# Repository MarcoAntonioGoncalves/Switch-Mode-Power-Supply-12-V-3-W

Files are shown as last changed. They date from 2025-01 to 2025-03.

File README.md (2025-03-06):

# Switch-Mode-Power-Supply-12-V-3-W

## Introduction

My name is Marco Antonio Machado Gonçalves, and I am a Mechatronics Engineering student at the Universidade Federal do Paraná (UTFPR). I created this repository to help anyone interested in designing a switched-mode power supply. It provides a comprehensive step-by-step guide, including the underlying theory, key equations, and criteria for selecting components. The repository also includes the circuits implemented on the PCB, along with the schematic and board files, as well as simulations and the results obtained

I think it’s important to highlight that the theoretical part does not provide an in-depth analysis of the mesh and operational stages of the circuits. As a consequence, the deduction of the design equations is also not presented. What is expected to be found in the theory is an explanation of how the circuit works and the necessary equations for designing it.

I would like to give credit to the book [Projeto de Fontes Chaveadas](https://ivobarbi.com.br/livro-projetos-de-fontes-chaveadas/) written by Ivo Barbi, and the YouTube playlist [Fontes Chaveadas](https://www.youtube.com/watch?v=BYBMHBqT8EI&list=PLSjlUAuQORNNm-O2ilwZME7qL0d8M-_xs). The book was a great help in the rectifier project and Dc-Dc converter project, while the YouTube channel provided detailed explanations and information about the design of switched-mode power supplies and high-frequency inductors. If anyone wants to dive deeper into the theory, I recommend these two sources.

## Recomendend order to read the repository

1. **Theory**
   - Start with the theoretical section to understand the main concepts.

2. **Simulations**
   - Review the simulations made in PSIM.

3. **Component Selection**
   - After the simulations, analyze the component selection.

4. **Results**
   - Explore the obtained results to understand the actual performance.

5. **Hardware Folder**
   - The hardware folder contains the following files:
     - Schematics
     - PCB files
     - 3D image of the PCB
   - These files are especially useful for those interested in building their own power supply.

## Specifications

<table align="center">
  <thead>
    <tr>
      <th><strong>Specification</strong></th>
      <th><strong>Description</strong></th>
      <th><strong>Unit</strong></th>
    </tr>
  </thead>
  <tbody>
    <tr>
      <td>Minimum Input Voltage</td>
      <td>110</td>
      <td>V</td>
    </tr>
    <tr>
      <td>Maximum Input Voltage</td>
      <td>233</td>
      <td>V</td>
    </tr>
    <tr>
      <td>Minimum Peak Voltage</td>
      <td>155.56</td>
      <td>V</td>
    </tr>
    <tr>
      <td>Maximum Peak Voltage</td>
      <td>329.51</td>
      <td>V</td>
    </tr>
    <tr>
      <td>Grid Frequency</td>
      <td>60</td>
      <td>Hz</td>
    </tr>
    <tr>
      <td>Output Power</td>
      <td>3</td>
      <td>W</td>
    </tr>
    <tr>
      <td>Output Voltage</td>
      <td>12</td>
      <td>V</td>
    </tr>
    <tr>
      <td>Efficiency</td>
      <td>80</td>
      <td>%</td>
    </tr>
    <tr>
      <td>Rectifier Ripple</td>
      <td>5</td>
      <td>%</td>
    </tr>
    <tr>
      <td>Switching Frequency</td>
      <td>66</td>
      <td>kHz</td>
    </tr>
    <tr>
      <td>Inductor Ripple</td>
      <td>0.25</td>
      <td>%</td>
    </tr>
    <tr>
      <td>Output Voltage Variation</td>
      <td>0.01</td>
      <td>V</td>
    </tr>
    <tr>
      <td>Safety Coefficient</td>
      <td>1.25</td>
      <td>-</td>
    </tr>
    <tr>
      <td>Ambient Temperature</td>
      <td>50</td>
      <td>ºC</td>
    </tr>
  </tbody>
</table>

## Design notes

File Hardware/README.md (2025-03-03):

# HADWARE

This session contains the hardware project files for the switch-mode power supply. The software used was Fusion 360. The files for download and images have been provided.

The objective was to design hardware that could be manufactured in a DIY manner, so the PCB contains larger pads and traces than would normally be necessary.

The method used for fabrication was the photographic method, which involves coating the copper board with photo-sensitive paint and transferring the circuit using ultraviolet light.

Below are images of the top and bottom layers of the PCB after fabrication. Unfortunately, the solder mask on the bottom layer had some defects, but it still served its purpose of facilitating the soldering process.

<p align="center">
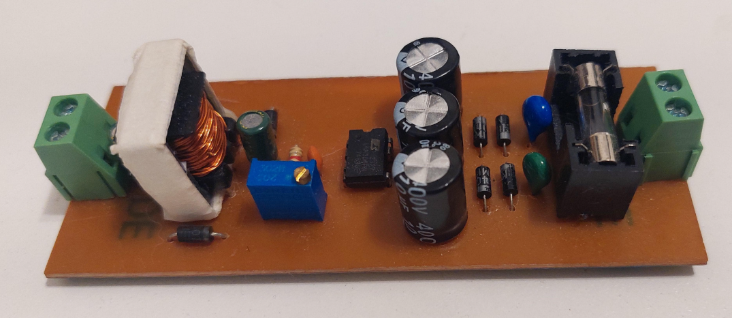
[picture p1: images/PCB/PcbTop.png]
Pcb Top
  
</p>

<p align="center">
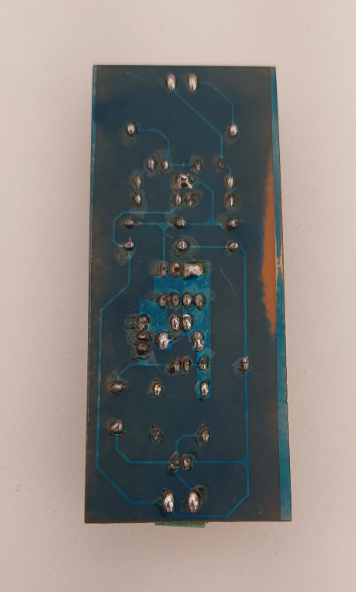
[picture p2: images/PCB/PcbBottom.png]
Pcb Bottom
  
</p>

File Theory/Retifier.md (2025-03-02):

# Full Wave Retifier

The design employs a full-wave rectifier with a capacitive filter. The equations for this design were derived from the book Projeto de Fontes Chaveadas by Ivo Barbi. A simplified analysis method was applied, which, while causing slight discrepancies between the simulated and calculated results, remains reliable for the design, especially considering that the ripple in the capacitor is kept under 20%.

# Equations

* ## Input Power
    $P_{\text{in}} = \frac{P_{\text{out}}}{\eta}$
* ## Filter Capacitor
    $C = \frac{P_{\text{in}}}{F_{\text{grid}} \left( V_{\text{peakMin}}^2 + V_{\text{cMin}}^2 \right)}$
* ## Reload Capacitor Time or Diode Conduction Time
    $t_c = \frac{\cos^{-1}\left( \frac{V_{\text{cMin}}}{V_{\text{peakMin}}} \right)}{2 F_{\text{grid}} \pi}$
* ## Peak Input Current
    $I_p = \frac{C \left( V_{\text{peakMin}} - V_{\text{cMin}} \right)}{t_c}$
* ## Rms Value of Alterned Component of Input Current
    $I_{\text{ClRms}} = I_p \sqrt{ 2 t_c F_{\text{grid}} - \left( 2 t_c F_{\text{grid}} \right)^2 }$
* ## Rms Output Current
    $I_{\text{outRms}} = \frac{P_{\text{in}}}{V_{\text{cMin}}}$
* ## Rms Capacitor Current
    $I_{\text{cRms}} = \sqrt{ I_{\text{outEfc}}^2 + I_{\text{Clef}}^2 }$
* ## Avarage Diode Current
    $I_{\text{dAvg}} = \frac{P_{\text{in}}}{2 V_{\text{cMin}}}$
* ## Rms Diode Current
    $I_{\text{dRms}} = I_p \sqrt{ \frac{t_c}{T} }$
* ## Peak Diode Current
    $I_{\text{dPeak}} = I_p$
* ## Max Diode Reverse Tension
    $V_{\text{dMax}} = V_{\text{peakMax}}$

# Theorical Results X Simulation Results

Analyzing the results, it is evident that the theoretical values closely match the simulated ones, except for the peak current. This discrepancy arises because, in the simplified analysis, the input current is assumed to have a rectangular waveform, whereas in practice, this is not the case. By examining the input current waveform, it becomes clear that it follows a triangular shape, corresponding to a segment of a cosine wave. According to the reference book, the actual peak current can be approximated as twice the theoretical value. In this project, this approximation results in a peak current of 0.490 A, which is remarkably close to the value obtained through simulation. To check the simulation values obtained, go to the  [simulations](../Simulations/Retifier.md) section.

<table align="center">
  <thead>
    <tr>
      <th><strong>Parameter</strong></th>
      <th><strong>Theoretical</strong></th>
      <th><strong>Simulation</strong></th>
      <th><strong>Unit</strong></th>
    </tr>
  </thead>
  <tbody>
    <tr>
      <td>Pin</td>
      <td>3.75</td>
      <td>3.75</td>
      <td>W</td>
    </tr>
    <tr>
      <td>Capacitance (C)</td>
      <td>26.48</td>
      <td>26.48</td>
      <td>µF</td>
    </tr>
    <tr>
      <td>Charging Time (tc)</td>
      <td>0.84</td>
      <td>0.80</td>
      <td>ms</td>
    </tr>
    <tr>
      <td>Peak Current (Ip)</td>
      <td>0.245</td>
      <td>0.492</td>
      <td>A</td>
    </tr>
    <tr>
      <td>Effective Output Current (IoutEfc)</td>
      <td>0.025</td>
      <td>0.026</td>
      <td>A</td>
    </tr>
    <tr>
      <td>Effective Capacitor Current (ICef)</td>
      <td>0.077</td>
      <td>0.088</td>
      <td>A</td>
    </tr>
    <tr>
      <td>Average Diode Current (IDmed)</td>
      <td>0.0126</td>
      <td>0.0107</td>
      <td>A</td>
    </tr>
    <tr>
      <td>Effective Diode Current (IDef)</td>
      <td>0.054</td>
      <td>0.059</td>
      <td>A</td>
    </tr>
    <tr>
      <td>Peak Diode Current (IDp)</td>
      <td>0.245</td>
      <td>0.493</td>
      <td>A</td>
    </tr>
    <tr>
      <td>Maximum Diode Voltage (Vdmáx)</td>
      <td>329.51</td>
      <td>329.51</td>
      <td>V</td>
    </tr>
  </tbody>
</table>

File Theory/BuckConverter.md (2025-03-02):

# Buck Converter

The non-isolated Buck Forward converter is a step-down voltage converter. It uses an electronic switch controlled by a PWM signal, and a combination of a diode and an inductor to decrease the output voltage in relation to the input. As the name suggests, there is no galvanic isolation between the power supply and the output of the circuit.

When it comes to DC-DC converters, there are three possible conduction modes: Continuous Conduction Mode (CCM), Discontinuous Conduction Mode (DCM), and Critical Conduction Mode (CRM), which refer to the current in the inductor. In CCM, the current never reaches zero; in CRM, the current reaches zero at the end of the cycle but quickly rises again; in DCM, the current in the inductor reaches zero and stays there for part of the cycle. Each mode leads to a different analysis of the circuit, causing the design equations to vary depending on the conduction mode used. For this project, Continuous Conduction Mode (CCM) will be considered.

# Equations

* ## Load Ro
  
    $$R_o = \frac{V_o^2}{P_o}$$

    $$i_{\text{Ro}} = \frac{V_o}{R_o}$$

* ## Dutty Cycle
  
    $$D_{\text{min}} = \frac{V_o}{V_{\text{xMin}}-\Delta V_{\text{Cin}}}$$

* ## Inductor 
    $$\Delta i_{\text{Lo}} = \Delta i_{\text{LoPercentage}} \cdot i_{\text{Ro}}$$

    $$L_o = D_{\text{min}}\left(\frac{V_{\text{peakMin}} - \Delta V_{\text{Cin}} - V_O}{F_s \Delta i_{\text{Lo}}}\right)$$

    $$i_{\text{LoMax}} = i_{\text{Ro}} \cdot \Delta i_{\text{Lo}}^2$$

    $$i_{\text{LoMed}} = i_{\text{Ro}}$$

    $$i_{\text{LoRms}} = \sqrt{\frac{\Delta i_{\text{Lo}}^2 + 12 i_{\text{Ro}}^2}{12}}$$
* ## Capacitor Co
    $$\Delta V_o = \Delta V_{\text{VoPercentage}}\cdot V_o$$

    $$C_o = \frac{2 \Delta i_{\text{Lo}} D_{\text{min}}}{\Delta V_o F_s}$$

    $$i_{\text{CoRms}} = \sqrt{\frac{\Delta i_{\text{Lo}}^2}{12}}$$
* ## Eletronic Switch
    $$i_{\text{sMax}} = i_{\text{Ro}} + \frac{\Delta i_{\text{Lo}}}{2}$$

    $$i_{\text{sMed}} = i_{\text{Ro}} \cdot D_{\text{min}}$$

    $$i_{\text{sRms}} = \sqrt{D_{\text{min}} \left( \frac{\Delta i_{\text{Lo}}^2 + 12 i_{\text{Ro}}^2}{12} \right)}$$

    $$V_{\text{sMax}} = V_{\text{peakMax}}$$
* ## Diode Do
    $$i_{\text{DoMax}} = i_{\text{Ro}} + \frac{\Delta i_{\text{Lo}}}{2}$$

    $$i_{\text{DoMed}} = i_{\text{Ro}} \cdot (1 - D_{\text{min}})$$

    $$i_{\text{DoRms}} = \sqrt{(1-D_{\text{min}}) \left( \frac{\Delta i_{\text{Lo}}^2 + 12 i_{\text{Ro}}^2}{12} \right)}$$

    $$V_{\text{DoMax}} = -V_{\text{peakMax}}$$

# Theoretical Results X Simulation Results

The theoretical results were very close to those obtained through simulation, proving the quality of the methodology used in this project. To check the simulation values obtained, go to the [simulations](../Simulations/BuckConverter.md) section.

<table align="center">
  <thead>
    <tr>
      <th><strong>Parameter</strong></th>
      <th><strong>Theoretical</strong></th>
      <th><strong>Simulation</strong></th>
      <th><strong>Unit</strong></th>
    </tr>
  </thead>
  <tbody>
    <tr>
      <td>Load Voltage Ro</td>
      <td>12</td>
      <td>11.97</td>
      <td>V</td>
    </tr>
    <tr>
      <td>Load Average Current Io</td>
      <td>0.25</td>
      <td>0.249</td>
      <td>A</td>
    </tr>
    <tr>
      <td>Minimum Duty Cycle</td>
      <td>0.081</td>
      <td>0.081</td>
      <td>-</td>
    </tr>
    <tr>
      <td>Inductor Current Ripple</td>
      <td>0.062</td>
      <td>0.060</td>
      <td>A</td>
    </tr>
    <tr>
      <td>Inductor Inductance Lo</td>
      <td>2.670</td>
      <td>2.670</td>
      <td>mH</td>
    </tr>
    <tr>
      <td>Inductor RMS Current</td>
      <td>0.250</td>
      <td>0.249</td>
      <td>A</td>
    </tr>
    <tr>
      <td>Inductor Maximum Current</td>
      <td>0.281</td>
      <td>0.280</td>
      <td>A</td>
    </tr>
    <tr>
      <td>Inductor Average Current</td>
      <td>0.250</td>
      <td>0.249</td>
      <td>A</td>
    </tr>
    <tr>
      <td>Output Voltage Ripple</td>
      <td>0.120</td>
      <td>0.09</td>
      <td>V</td>
    </tr>
    <tr>
      <td>Output Capacitance Co</td>
      <td>1.280</td>
      <td>1.280</td>
      <td>µF</td>
    </tr>
    <tr>
      <td>Capacitor RMS Current</td>
      <td>0.018</td>
      <td>0.018</td>
      <td>A</td>
    </tr>
    <tr>
      <td>Switch Maximum Current S</td>
      <td>0.281</td>
      <td>0.280</td>
      <td>A</td>
    </tr>
    <tr>
      <td>Switch Average Current S</td>
      <td>0.020</td>
      <td>0.020</td>
      <td>A</td>
    </tr>
    <tr>
      <td>Switch RMS Current S</td>
      <td>0.071</td>
      <td>0.071</td>
      <td>A</td>
    </tr>
    <tr>
      <td>Switch Maximum Voltage</td>
      <td>329.511</td>
      <td>329.51</td>
      <td>V</td>
    </tr>
    <tr>
      <td>Diode Maximum Current Do</td>
      <td>0.281</td>
      <td>0.280</td>
      <td>A</td>
    </tr>
    <tr>
      <td>Diode Average Current Do</td>
      <td>0.229</td>
      <td>0.229</td>
      <td>A</td>
    </tr>
    <tr>
      <td>Diode RMS Current Do</td>
      <td>0.240</td>
      <td>0.239</td>
      <td>A</td>
    </tr>
    <tr>
      <td>Diode Maximum Voltage</td>
      <td>-329.511</td>
      <td>-329.51</td>
      <td>V</td>
    </tr>
  </tbody>
</table>

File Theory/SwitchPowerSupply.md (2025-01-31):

## Switch Power Supplys

Switching power supplies are electrical devices that convert energy from one form to another using electronic switching, typically with transistors, to control the flow of current. They are highly efficient because they operate at high frequencies, minimizing energy losses and allowing for a compact design. The process involves rectifying alternating current (AC) to direct current (DC), followed by fast switching control and filtering to reduce ripple in the output, using a Dc-Dc Converter.

It's circuit can be simplified into a few main parts. A rectifier, which serves to convert alternating current (AC) into direct current (DC), a DC-DC converter, which reduces the input voltage, and a control circuit, which maintains the output voltage at the desired value and generetes the PWM to the eletronic switch.
There are also RF filters, but they are not implemented in this project.

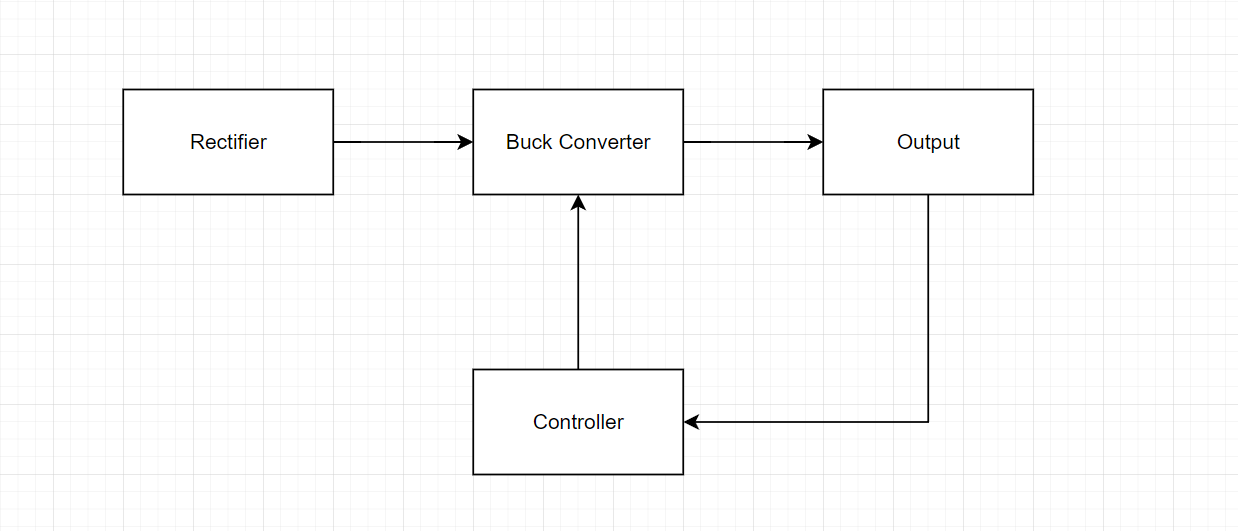
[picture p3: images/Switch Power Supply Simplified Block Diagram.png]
Simplified Block Diagram


Switching power supplies are generally superior to linear power supplies due to their higher efficiency, smaller size, and lower heat dissipation. Unlike linear regulators, which dissipate excess energy as heat, switching power supplies use high-frequency switching circuits to regulate voltage with minimal energy loss. This results in significantly higher efficiency, often exceeding 80-90%, compared to linear supplies, which typically operate at around 50% efficiency or lower. Additionally, switching power supplies are more compact and lightweight because they require smaller transformers and heatsinks. These advantages make them ideal for modern electronic applications, including embedded systems, battery-powered devices, and industrial equipment.

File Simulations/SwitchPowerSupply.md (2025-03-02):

# Switch Power Supply Circuit

## Circuit

For the switched-mode power supply circuit, commercial component values were used; therefore, the values differ from the simulations of the converter and the rectifier. Since the input voltage frequency is 60 Hz and the switching frequency is 66 kHz, it was challenging to choose a suitable time step to accurately visualize every part of the circuit. Therefore, for the rectifier, only the output voltage and current parameters will be included in this file.

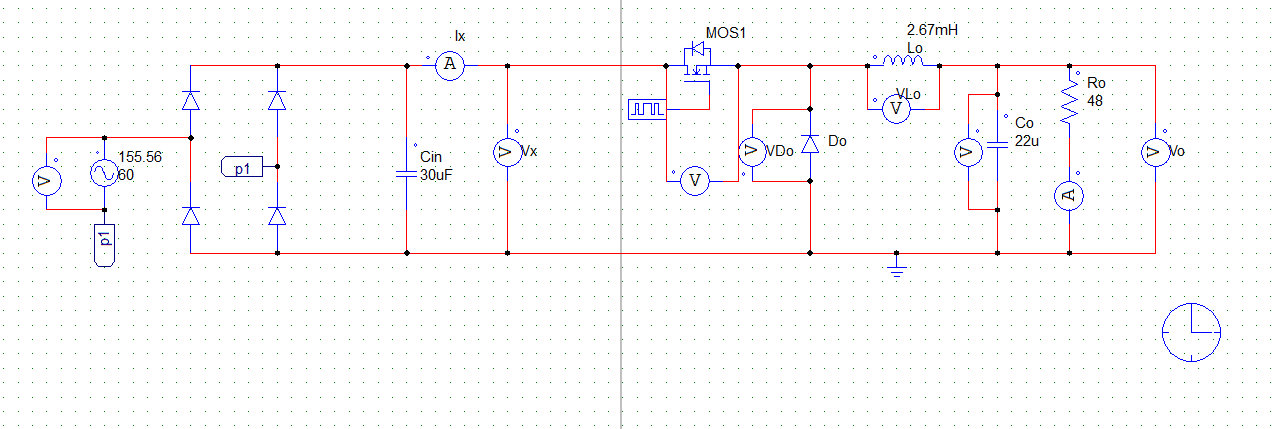
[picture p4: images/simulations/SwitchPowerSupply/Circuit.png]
Power Supply Circuit


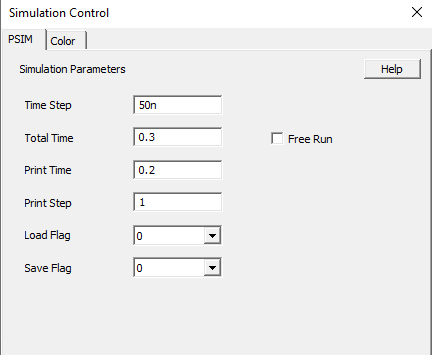
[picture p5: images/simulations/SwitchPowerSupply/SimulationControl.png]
Simulation Control


## Retifier Output
### Vx
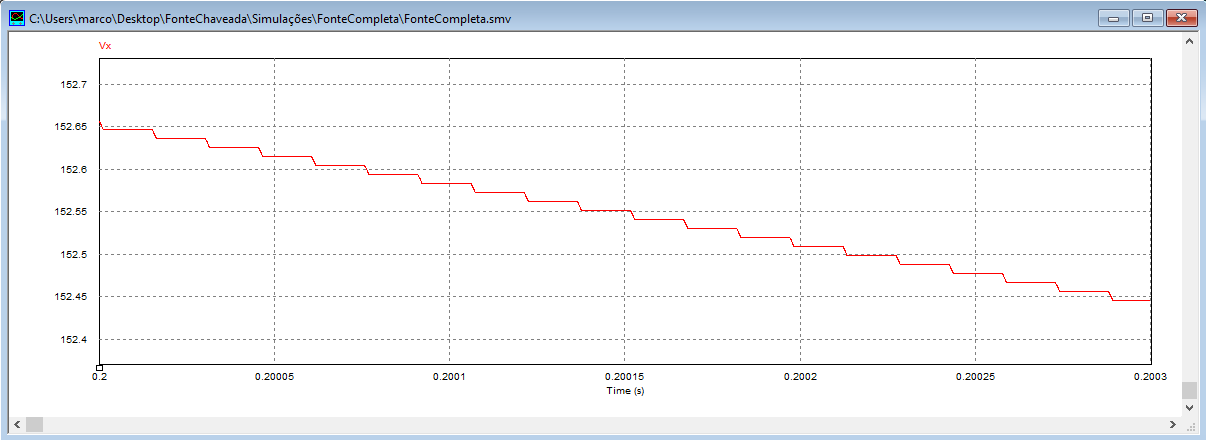
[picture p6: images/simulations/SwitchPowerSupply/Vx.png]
Output Voltage

### Ix
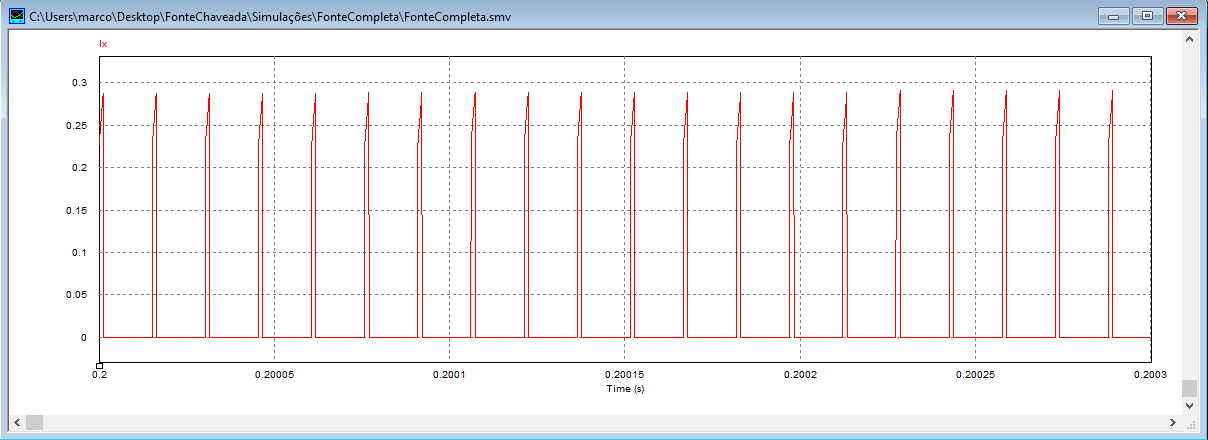
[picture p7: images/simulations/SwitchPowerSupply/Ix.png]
Output Current


## Load Ro
### Vo
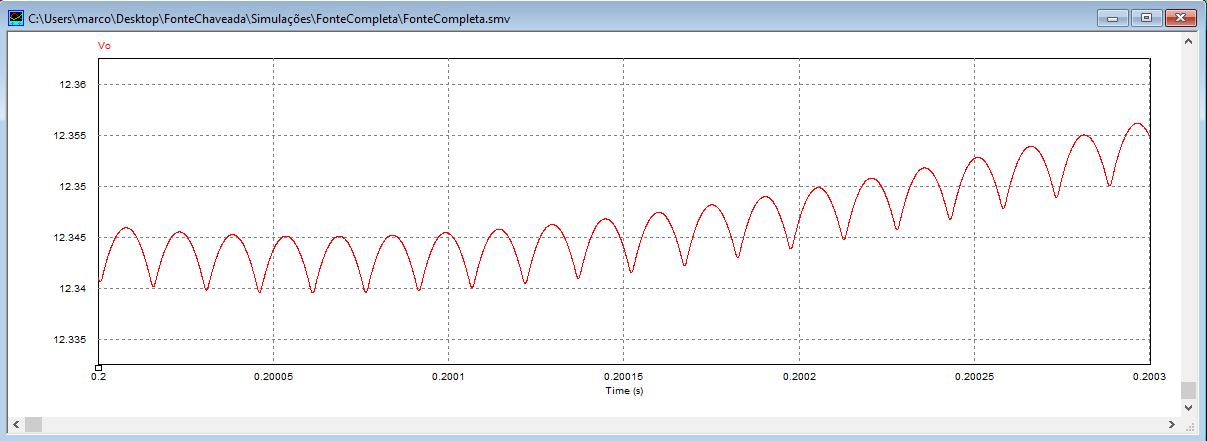
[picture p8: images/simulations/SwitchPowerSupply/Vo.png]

### Io
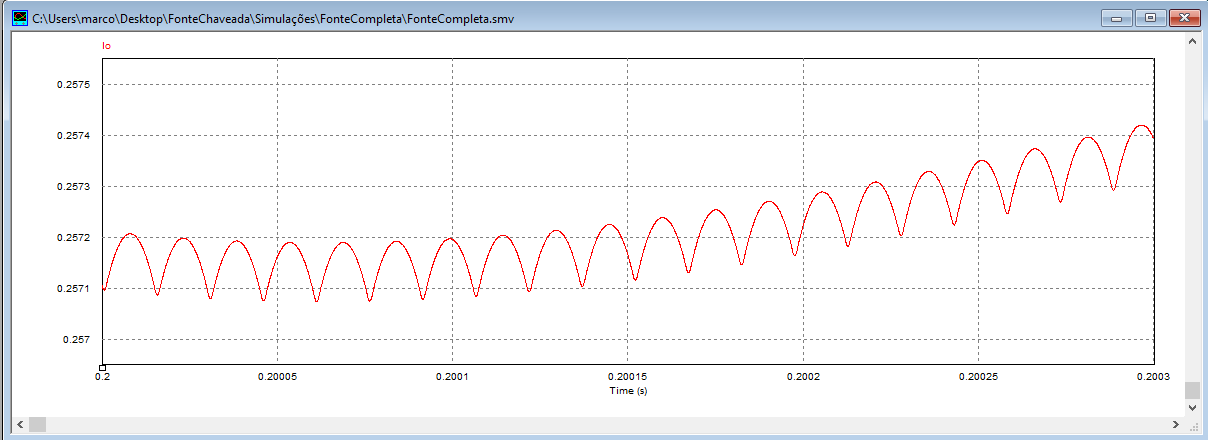
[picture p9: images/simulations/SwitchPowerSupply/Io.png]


## Inductor Lo
### VLo
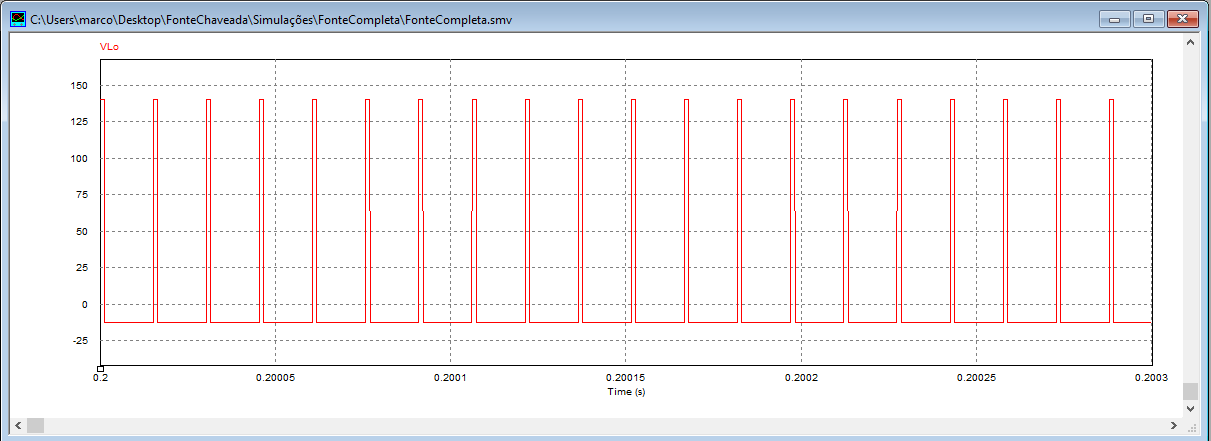
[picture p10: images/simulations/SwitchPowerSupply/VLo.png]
Voltage in Inductor Lo

### ILo
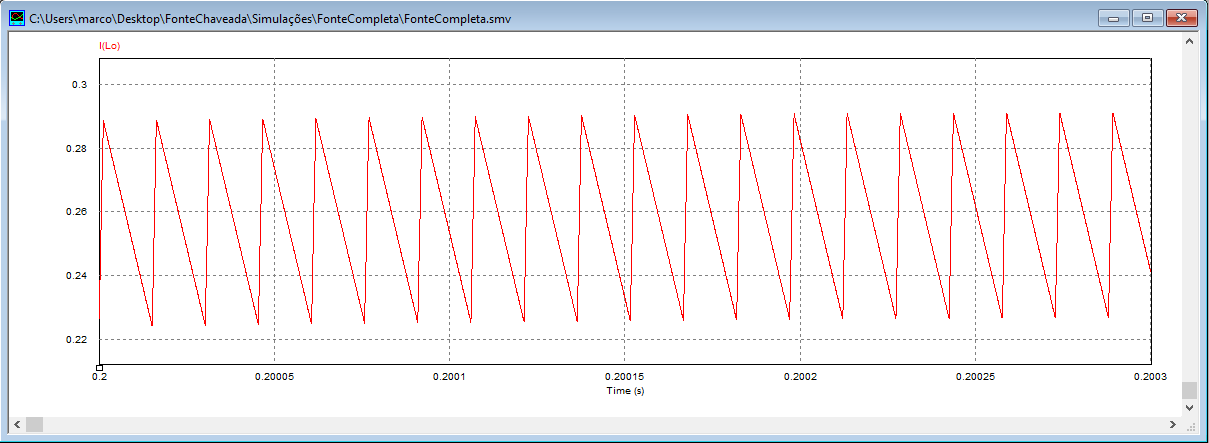
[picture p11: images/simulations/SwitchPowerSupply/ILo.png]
Current in Inductor Lo


## Capacitor Co
### VCo
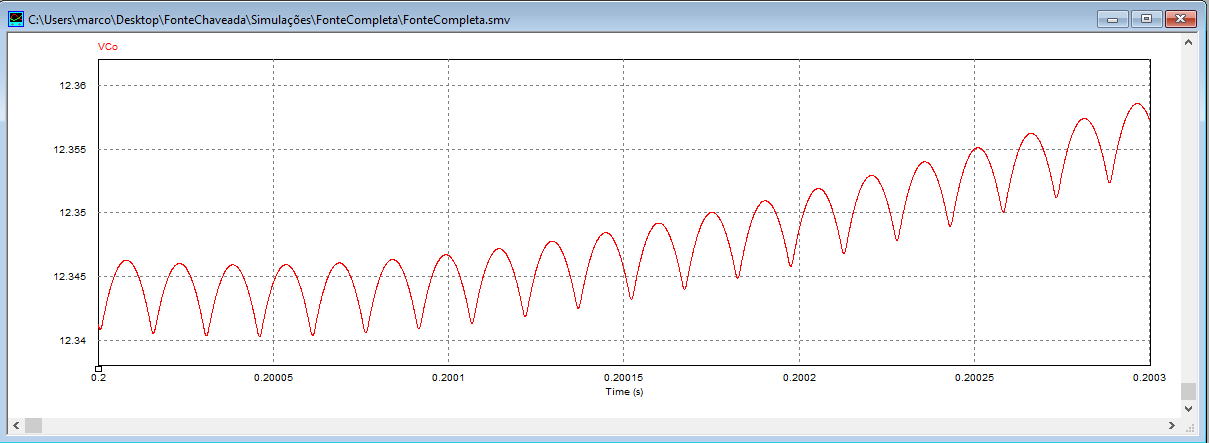
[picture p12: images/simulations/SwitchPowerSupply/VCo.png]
Voltage in Capacitor Co

### ICo
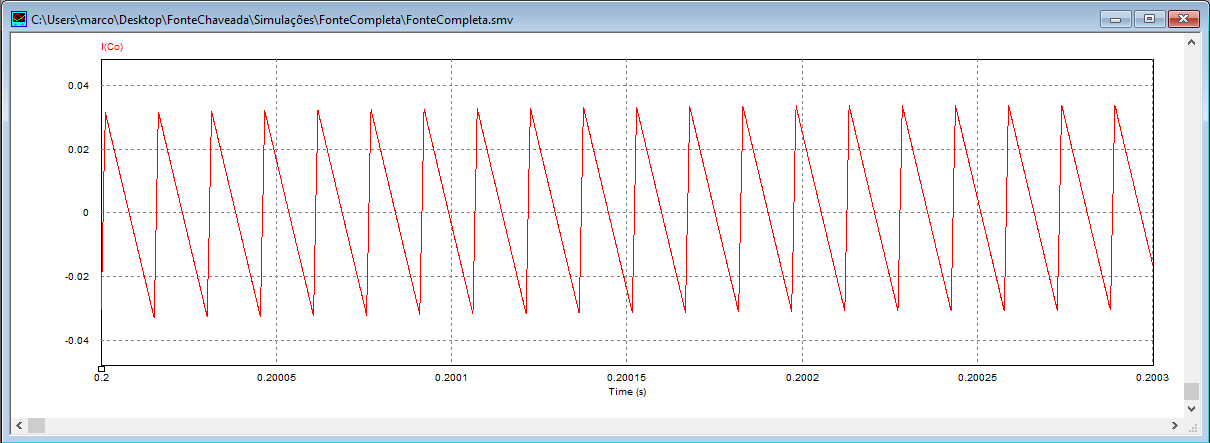
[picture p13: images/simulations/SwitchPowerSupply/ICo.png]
Current in Capacitor Co


## Mosfet
### Vmosf
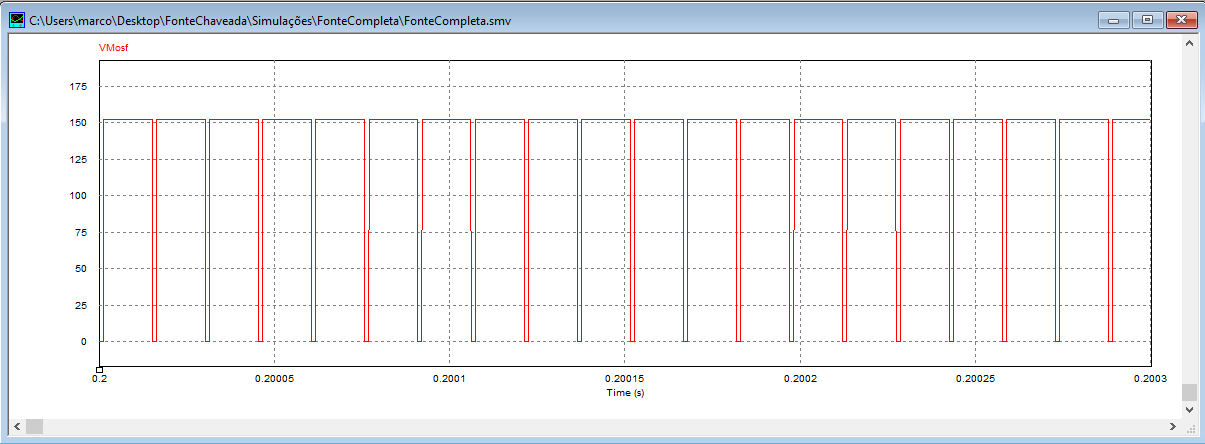
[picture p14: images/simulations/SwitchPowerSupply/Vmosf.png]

### Imosf
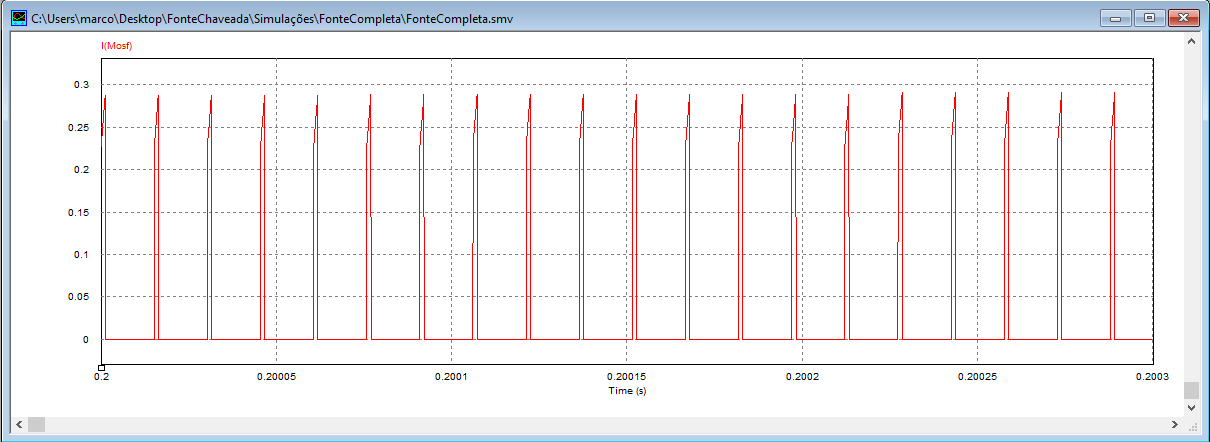
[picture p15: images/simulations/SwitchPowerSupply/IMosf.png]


## Doide Do
### VDo
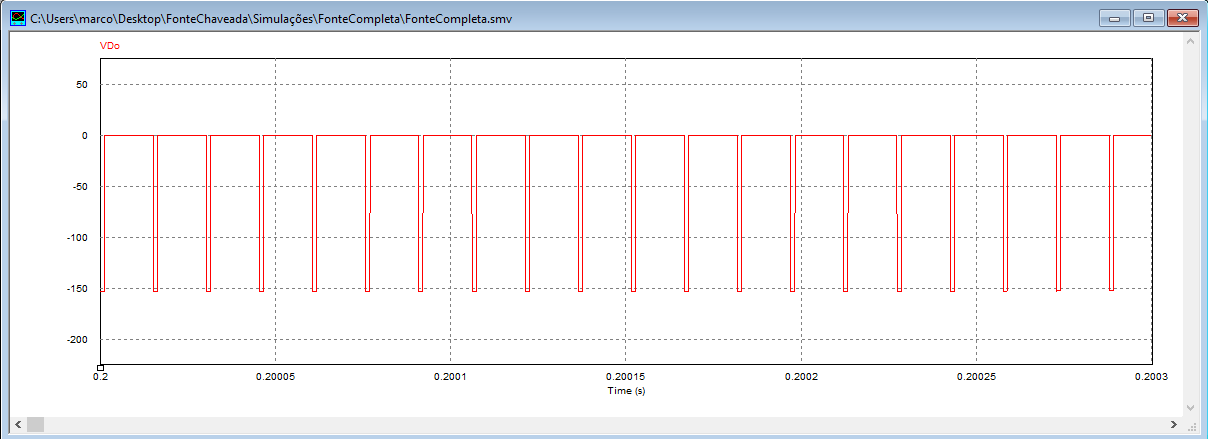
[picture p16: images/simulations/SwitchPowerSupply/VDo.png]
Voltage in Diode Do

### IDo
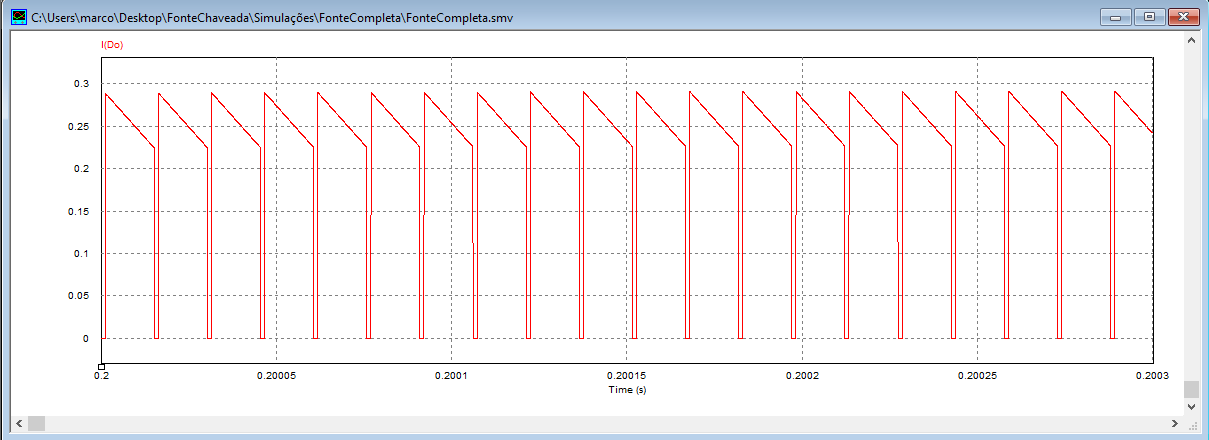
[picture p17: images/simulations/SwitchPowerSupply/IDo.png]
Current in Diode Do


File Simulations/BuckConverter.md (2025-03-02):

# Buck Converter Simulations

## Circuit

The simulation was performed for the minimum input voltage specified. The component values calculated were based on theoretical calculations. 

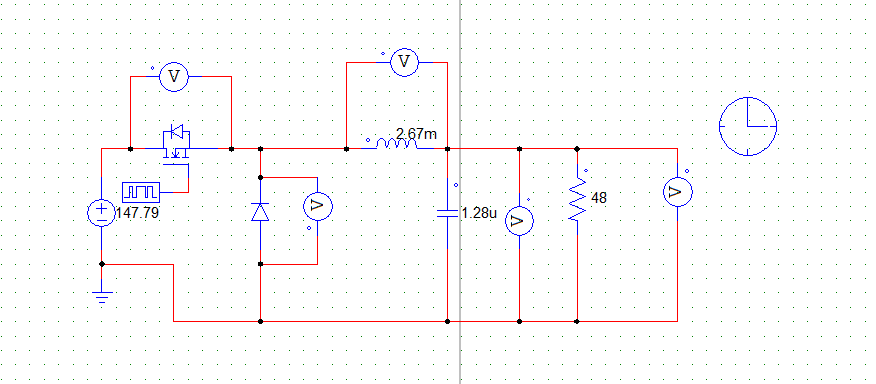
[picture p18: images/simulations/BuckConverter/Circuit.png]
Buck Conversor Circuit


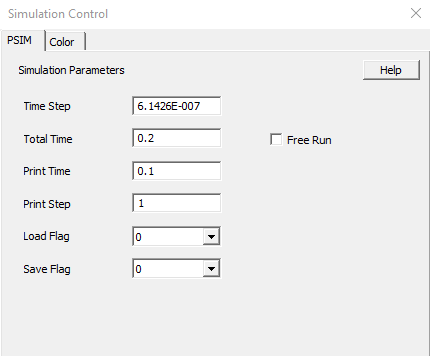
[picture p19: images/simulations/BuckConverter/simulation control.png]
Simulation Control


## Load Ro
### Vo
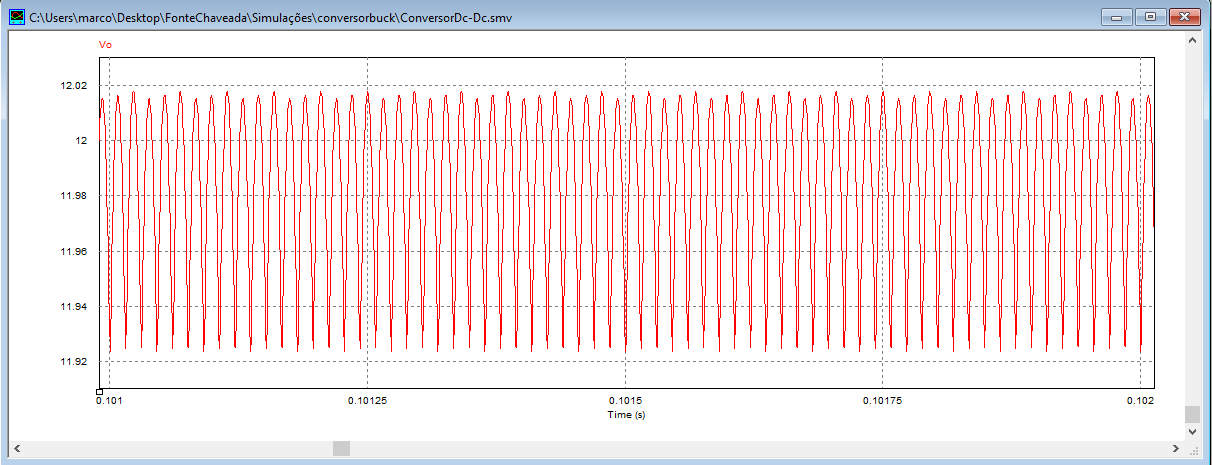
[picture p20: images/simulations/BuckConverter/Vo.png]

### Io
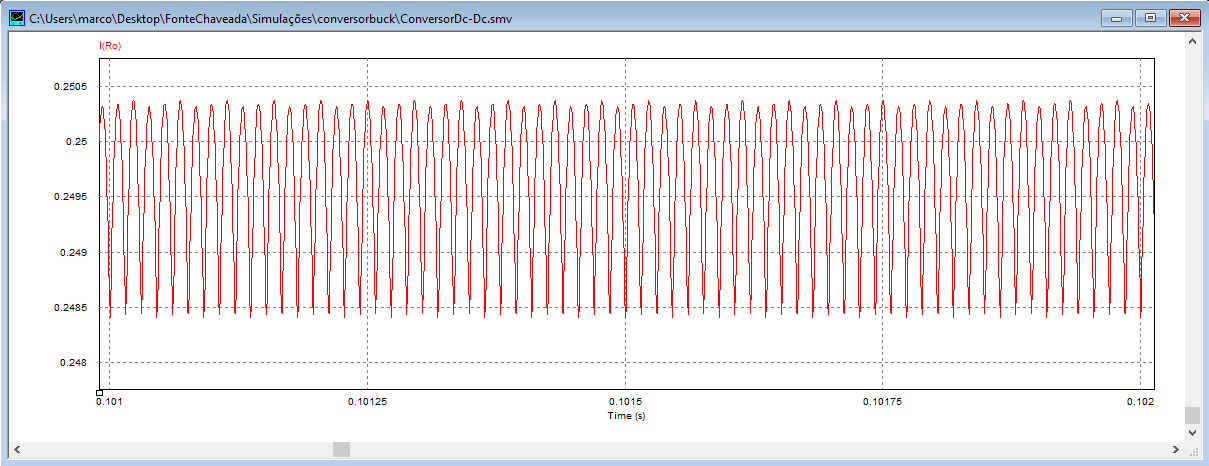
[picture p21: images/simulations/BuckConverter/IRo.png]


## Inductor Lo
### VLo
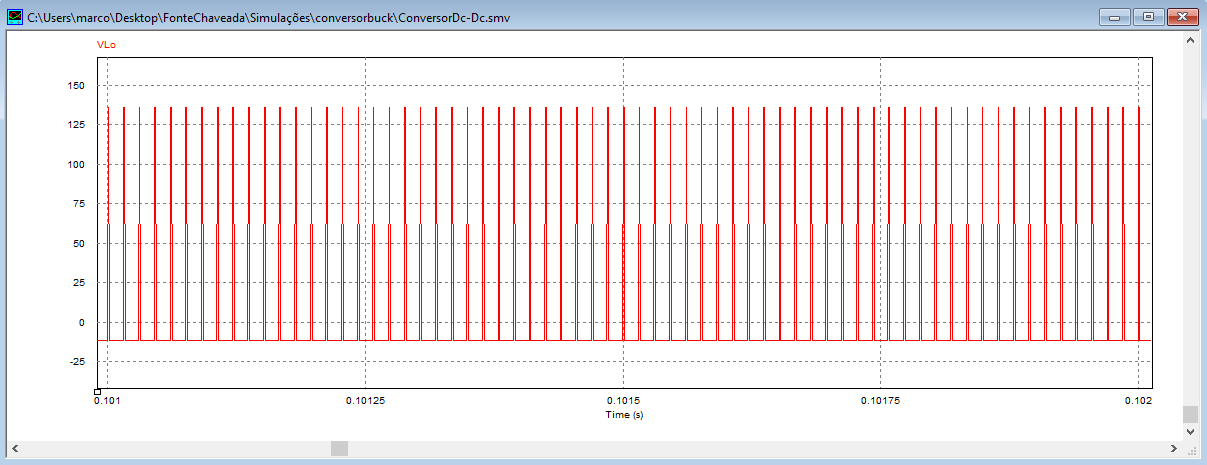
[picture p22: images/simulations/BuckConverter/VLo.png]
Voltage in Inductor Lo

### ILo
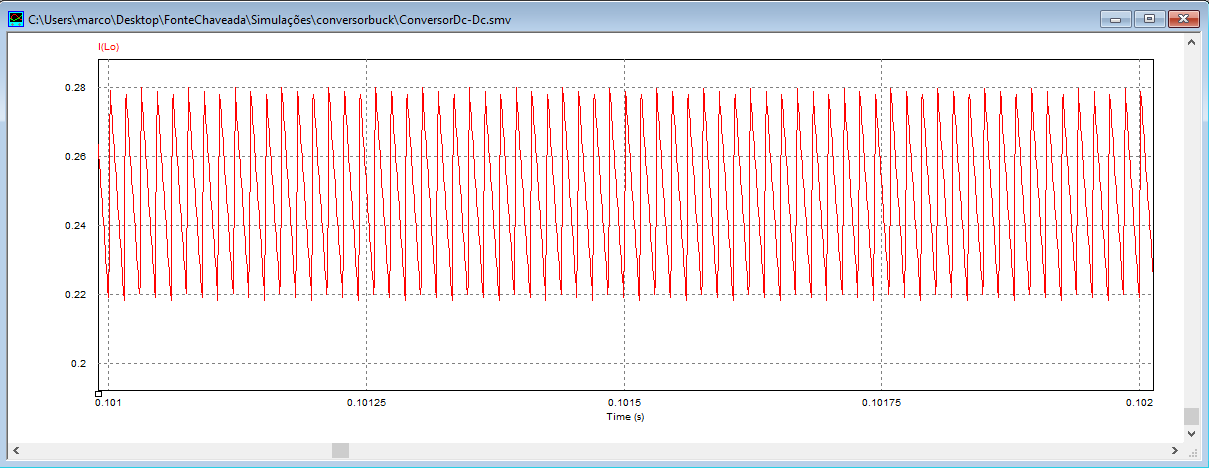
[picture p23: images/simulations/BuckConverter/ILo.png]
Current in Inductor Lo


## Capacitor Co
### VCo
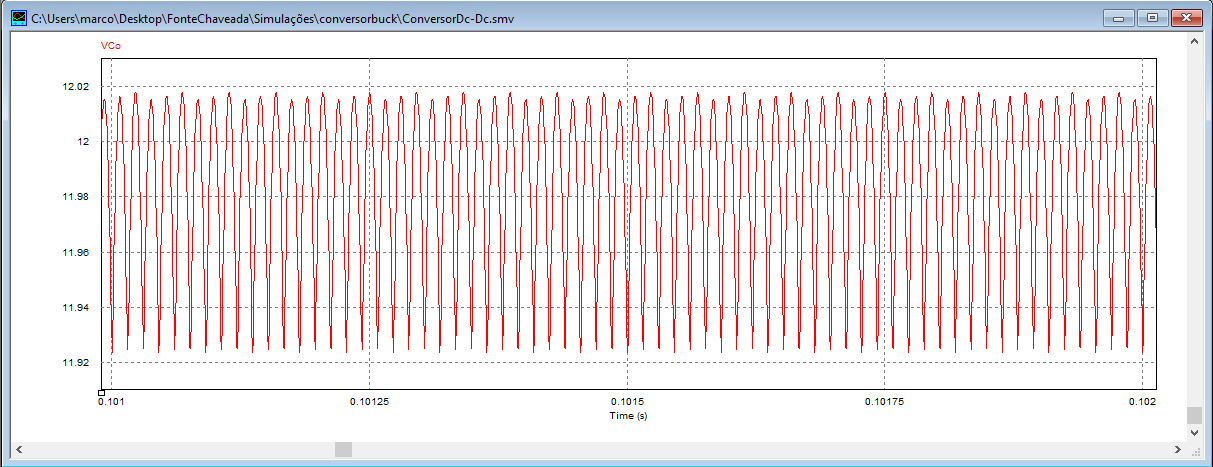
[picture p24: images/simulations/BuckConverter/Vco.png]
Voltage in Capacitor Co

### Io
Current in Capacitor Co

## Mosfet
### Vmosf
Voltage in Load Ro
### Imosf
Current in Load Ro

## Doide Do
### VDo
Voltage in Diode Do
### IDo
Current in Diode Do

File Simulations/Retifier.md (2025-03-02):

# Retifier Simulations

## Circuit

The simulation was performed for the minimum input voltage specified. The component values calculated were based on theoretical calculations.
Retifier Circuit

Simulation Control

## Output

### Vout

Output Voltage

### Iout

Output Current

## Diode Din

### VDin

Voltage in Doide Din

### IDin

Current in Diode Din

## Capacitor Cin

### VCin

Voltage in Capacitor Cin

### ICin

Current in Capacitor Cin

## Input

### Vin

Input Voltage

### Iin

Input Current

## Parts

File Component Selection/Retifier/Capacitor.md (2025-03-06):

# Capacitor 

Just like in the DC-DC converter, the filter capacitor must have a nominal voltage higher than the peak voltage of the power supply, withstand an effective current greater than the one flowing through it, and have a capacitance value greater than the calculated one. However, unlike the DC-DC converter, the capacitor for the rectifier does not need to be from the AX series and can be a general-purpose capacitor.

The capacitance calculation resulted in 26.48 µF, so three 10 µF capacitors will be used in parallel, resulting in a total capacitance of 30 µF. The nominal voltage, after applying the safety coefficient, is 411 V, and the effective current flowing through the component is 0.088 A, which results in 0.110 A with the safety coefficient applied.

A 400 V capacitor will be selected. Although this is slightly lower than the calculated value, it should still perform adequately since the maximum voltage of the power supply without the safety coefficient is 329.51 V.

The selected capacitors are from Nichicon, and below is an image from the datasheet.

<p align="center">
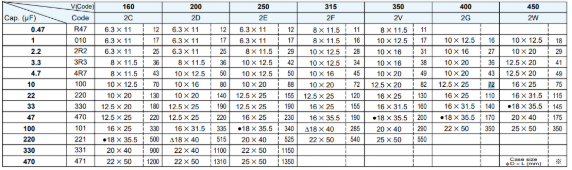
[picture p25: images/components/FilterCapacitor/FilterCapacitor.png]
Nichicon datasheet
  
</p>

It is observed that a Nichicon 10 µF 400V capacitor can withstand an RMS current of 72 mA, which is lower than the calculated value. Therefore, multiple capacitors are required to handle the effective current. Since three capacitors are being used in parallel, the maximum current capacity of the combination is 216 mA, which is more than sufficient even after applying the safety coefficient.

Although the voltage on the capacitor with the safety coefficient is slightly higher than the component's voltage, it will still be used, as it is much higher than the worst-case voltage without the safety coefficient.

Unfortunately, the datasheet does not provide information on the equivalent series resistance (ESR) for capacitors with a nominal voltage above 100V. Therefore, for loss calculations, the ESR value for a 10 µF 100V capacitor will be used, which is 1.8 Ω.

Since the three capacitors are in parallel, the current will be evenly divided among them, and each capacitor will experience the same power dissipation. The formulas for this calculation have already been discussed in buck converter section.

<table align="center">
  <thead>
    <tr>
      <th><strong>Parameter</strong></th>
      <th><strong>Simulated/Calculated</strong></th>
      <th><strong>Safety Coefficient</strong></th>
      <th><strong>Component</strong></th>
    </tr>
  </thead>
  <tbody>
    <tr>
      <td>Capacitance (µF)</td>
      <td>26.48</td>
      <td>X</td>
      <td>30</td>
    </tr>
    <tr>
      <td>Nominal Voltage (V)</td>
      <td>329.51</td>
      <td>411.88</td>
      <td>400</td>
    </tr>
    <tr>
      <td>Irms (A)</td>
      <td>0.088</td>
      <td>0.110</td>
      <td>0.216</td>
    </tr>
    <tr>
      <td>Dissipated Power (W)</td>
      <td>0.0046</td>
      <td>X</td>
      <td>X</td>
    </tr>
  </tbody>
</table>

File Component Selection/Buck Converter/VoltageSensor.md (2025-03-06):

# Voltage Sensor

The LKN-306 IC operates as a closed-loop control system, with feedback from the voltage sensor. According to the component's datasheet, the PWM adjustment is always made in such a way that the voltage at the feedback pin is 1.65V. To achieve this, a voltage divider should be designed using two resistors so that, with the specified output voltage of the source (12V), the voltage at the feedback pin will be 1.65V.

<p align="center">
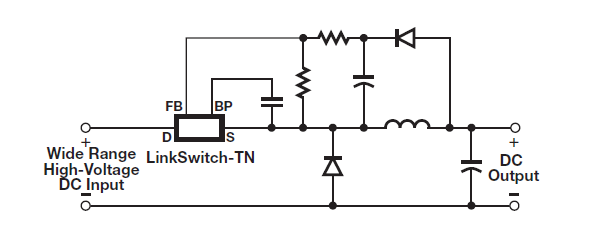
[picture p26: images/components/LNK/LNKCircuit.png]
Datasheet Circuit
  
</p>

A diode and capacitor are added to replicate the output voltage in the voltage divider, it was used the same components from the Buck Converter. The voltage divider results in R1 being 13.8 kΩ and R2 being 2.2 kΩ. A 10kΩ potentiometer will be used for R1, allowing the output voltage of the power supply to be adjustable.

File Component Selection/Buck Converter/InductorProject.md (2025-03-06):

# Inductor Project

Inductors are crucial components for the operation of a DC-DC converter. When operating at high frequencies, these components can exhibit a range of non-idealities, potentially leading to undesirable results such as voltage spikes, high losses, and noise emission.

Unlike other components, the inductor will not be purchased as a finished product but rather constructed from an EE-type ferrite core and enameled copper wire. The design equations were taken from a paper guided by Professor Ivo Barbi called: [Projeto Físico de Indutores e Transformadores](https://professorpetry.com.br/Bases_Dados/Apostilas_Tutoriais/Apostila_Projeto_Fisico_De_Magneticos.pdf), which shows how to build magnetic elements for high-frequency operation.

This section will discuss the selection of the magnetic core, the choice of the enameled copper wire type, and the necessary parameters for the construction of the inductor. It is important to note that the inductance of the inductor was previously calculated and should be 2.670 mH.

## Product of the Areas Ae and Aw

The product of the areas Ae and Aw is of utmost importance in the selection of the magnetic core used, as it determines the energy storage capacity, magnetic efficiency, and thermal performance.

<p align="center">
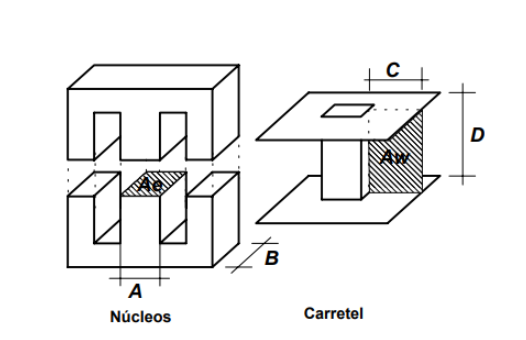
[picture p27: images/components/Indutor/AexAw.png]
Ae x Aw
  
</p>

A component present in the inductor that has not been mentioned yet is the spool, where the core will be inserted and the wire will be wound.

The minimum product of the areas that the core must have is calculated according to the equation below:

$$ A_e \cdot A_w = \frac{L_o \cdot i_{LoRms} \cdot i_{LoMax}}{\Delta B \cdot J_{max} \cdot K_w} $$

The parameters not yet mentioned in this equation are those in the denominator. $J_{\text{max}}$ represents the maximum current density in the inductor, $K_w$ represents the area utilization factor that will actually be used by the copper winding, and $\Delta B$ represents the magnetic flux density of the EE-type ferrite core. For $K_w$ and $J_{\text{max}}$, there are typical values that are widely used by designers. For the first, the value is 0.7, and for the second, it is 450 A/cm². As for $\Delta B$, it is necessary to consult manufacturers' datasheets to obtain it. Below is an image from a catalog by Thorton, a company that manufactures magnetic cores.

<p align="center">
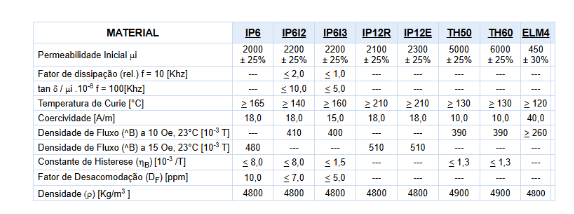
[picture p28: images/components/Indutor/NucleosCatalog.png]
Magnetic Cores
  
</p>

Through the catalog, it is possible to notice that the flux density of the IP12R material (the material of the core that will be acquired) is 0.510 T. This value could be used as $\Delta B$, but to allow for a safety margin, the value used will be 0.35.

With all the acquired values, it is possible to find the product between the areas $A_e$ and $A_w$.

<table align="center">
  <thead>
    <tr>
      <th><strong>Parameter</strong></th>
      <th><strong>Value</strong></th>
      <th><strong>Unit</strong></th>
    </tr>
  </thead>
  <tbody>
    <tr>
      <td>ΔB (Magnetic Flux Density)</td>
      <td>0.35</td>
      <td>T (Tesla)</td>
    </tr>
    <tr>
      <td>Kw (Area Utilization Factor)</td>
      <td>0.7</td>
      <td>-</td>
    </tr>
    <tr>
      <td>Jmax (Maximum Current Density)</td>
      <td>450</td>
      <td>A/cm²</td>
    </tr>
    <tr>
      <td>Ae × Aw (Product of Areas)</td>
      <td>0.0171</td>
      <td>cm⁴</td>
    </tr>
  </tbody>
</table>

The product of the areas of the selected core must be at least the value calculated above, taking care to avoid over-dimensioning, which would increase the project costs unnecessarily.

Thornton offers a catalog with various options for magnetic cores. From this document, several options were analyzed, and the NEE-20/10/5 was selected. It has an area product of 0.07905 cm⁴, which is slightly larger than the calculated value but not as large as other options found. Additionally, it is a relatively inexpensive component, making it ideal for use in the project.

<p align="center">
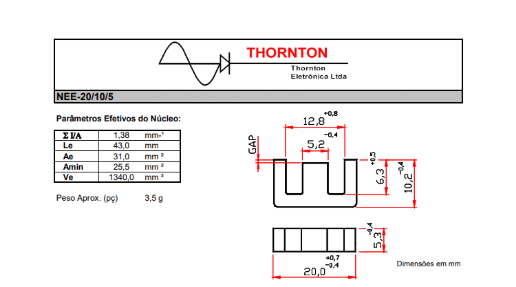
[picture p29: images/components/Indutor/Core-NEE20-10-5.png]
Core NEE-20/10/5
  
</p>

## Number of Turns

The inductor is constructed by winding an enameled copper wire around a spool, and then introducing the magnetic core with a certain gap to result in the desired inductance. The expression below calculates the number of turns the inductor should have, i.e., how many loops are required around the spool to achieve the calculated value.

$$ N_e = \frac{L_o \cdot i_{\text{LoMax}}}{\Delta B \cdot A_e} $$

The equation results in 69.29 turns. Since the number of turns must be an integer, the nearest whole number will be chosen, so 69 turns will be wound around the spool.

## Air gap

The air gap refers to the distance between the legs of the magnetic core. Below is an image to better illustrate it:

<p align="center">
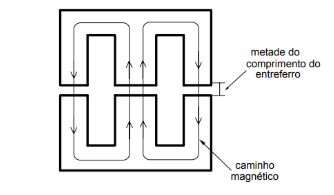
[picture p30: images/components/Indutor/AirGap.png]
Air Gap
  
</p>

The air gap is added mainly for two reasons. Without it, the inductance is only proportional to the magnetic permeability of the core, which can easily change due to temperature and operating point. Adding an air gap introduces a reluctance, which is the opposition to the passage of magnetic flux, much higher, making the inductance value less influenced by variations in the core's permeability. The other reason is that it allows the inductor to operate with higher currents in the winding without the core reaching saturation.

The distance of the air gap can be calculated using the expression below:

$$ \text{AirGap} = \frac{N^2 \cdot A_e \cdot \mu_o}{L_o} $$

The new parameter that appears in the equation is the magnetic permeability of air, which has the known value of $4\pi \times 10^{-7}$. By calculating the air gap distance, the obtained value is 0.07 millimeters.

Obviously, it will be extremely difficult to achieve such a small distance manually. What will be done in practice is placing a thin material between the legs of the core pair, such as a small piece of paper, and pressing the assembly until the desired inductance is achieved. Once it is obtained, tape will be applied to the inductor to secure the assembly.

## Enamelled Copper Wire

For high-frequency projects, the skin effect must be taken into account when choosing a conductor. This effect, causes electrons inside a conductor to tend to distribute along the periphery, resulting in a higher current density at the edges of the conductor than in the central region. This effect reduces the effective area of the conductor. Thus, it is possible to use an equation to calculate the maximum diameter the conductor can have.

$$ D_{\text{max}} = \frac{15}{\sqrt{F_s}} $$

This equation provides the result in centimeters and uses only the switching frequency as a parameter. The maximum diameter resulted in 0.058 centimeters. Thus, the wire gauge chosen cannot exceed this value.

The book *Projeto de Fontes Chaveadas* by Professor Ivo Barbi provides a table with relevant information about enamel-coated wires.

<p align="center">
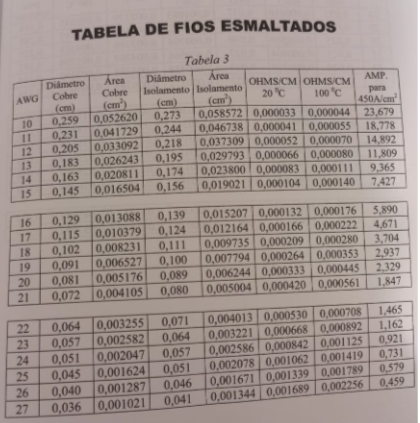
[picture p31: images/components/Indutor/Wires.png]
enamel-coated wires
  
</p>

It is possible to observe the copper diameter in the second column of the table. For this project, the chosen enamel-coated wire is AWG 26.
To determine whether a single wire or a combination will be necessary, it is required to calculate the minimum area needed for the effective current dimensioned in the project to flow through the inductor. After this calculation, simply divide the calculated required area by the copper area of the conductor, which is present in the table. The equations to obtain the answers are shown below:

$$ A_{\text{necessary}} = \frac{i_{\text{LoRms}}}{J_{\text{max}}} $$

$$ N_{\text{wires}} = \frac{A_{\text{necessary}}}{A_{\text{table}}} $$

The minimum area required calculated was 5.57E-04 cm², and the conductor area from the AWG 26 table is 0.001287 cm². Solving for the number of wires, we obtain a value of 0.43. Therefore, it will not be necessary to use a parallel wire configuration; a single wire will be sufficient to comfortably conduct the effective current circulating through the inductor.

## Inductor Losses  
As was done for the other components, it is necessary to calculate the losses that occur in the inductor. These losses are composed of copper losses due to Joule's effect, and magnetic losses, which occur in the core.

### Copper Losses
To calculate the copper losses, it is necessary to first calculate the 
resistance presented by the winding:

$$ R_{\text{cooper}} = \frac{R_{\text{wire}} \cdot L_{\text{turn}} \cdot N}{N_{\text{fios}}} $$

The new parameters that appear in this equation are the resistance of the wire and the average length of a turn. The first is obtained from figure from the book, and the worst-case scenario will be used, with a conductor temperature of 100°C. The resistance value in this case is 0.001419 Ω. The second is taken from the Thornton datasheet, and its value is 4.3 centimeters. Solving this gives a resistance of approximately 0.422 Ω.
With the resistance value, we can use the well-known power equation that relates resistance and current:

$$ P = R_{\text{cooper}} \times I_{\text{LoRms}}^2 $$

By performing the calculation, it is possible to observe that the loss is 0.026 W.

### Magnetic Losses
According to Ivo Barbi, the magnetic losses are related to hysteresis and can be calculated through an empirical expression:

$$ P = \Delta B^{2.4} \cdot (K_h \cdot f_s + K_f \cdot F_s^2) \cdot Volume_{\text{core}} $$

In this equation, there are some parameters that have not yet been presented in this document, which are $K_h$, $K_f$, and the volume of the core. The values of $K_h$ and $K_f$ are respectively $4 \times 10^{-5}$ and $4 \times 10^{-10}$. These values were taken from Ivo Barbi's material, and according to him, they are standard values for Thornton cores. The core volume is taken from the datasheet, with a value of $1.34 \, \text{cm}^3$. The expression results in $0.472 \ \text{W}$.

### Total losses

The total losses are calculated with the equation bellow. For this inductor it results in 0,498W.

$$ P_{\text{total}} = P_{\text{magnetic}} + P_{\text{cooper}}$$

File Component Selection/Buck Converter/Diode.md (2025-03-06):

## Diode Do

The diode chosen for the converter must be capable of conducting the average current with a certain safety margin and withstand a reverse voltage greater than the maximum reverse voltage calculated previously. Another important point is the reverse recovery time, which is a very important parameter when this component operates at high frequencies.

Reverse recovery time is the time required for the diode to stop conducting current after the voltage is reversed. This occurs because there is a parasitic capacitance in parallel with the diode, causing the component to stop conducting only after the capacitance is completely discharged. This time can be a limiting factor for high-frequency operation, so the component must have a reverse recovery time smaller than the designed value. Diodes with this characteristic belong to the ultra-fast family, so the chosen component will belong to this class.

The maximum reverse operation time was obtained according to a rule of thumb used by many designers:

$$ T_{rr} < \frac{1}{f_s} \cdot 0.005 $$

<table align="center">
  <thead>
    <tr>
      <th><strong>Parameter</strong></th>
      <th><strong>Value</strong></th>
      <th><strong>Unit</strong></th>
    </tr>
  </thead>
  <tbody>
    <tr>
      <td>Reverse Recovery Time (nS)</td>
      <td>75.75</td>
      <td>nS</td>
    </tr>
    <tr>
      <td>Maximum Reverse Voltage (V)</td>
      <td>-411.89</td>
      <td>V</td>
    </tr>
    <tr>
      <td>Average Current (A)</td>
      <td>0.287</td>
      <td>A</td>
    </tr>
  </tbody>
</table>

It should be noted that the values are higher than they would typically be because a safety coefficient of 1.25 was applied, making the design more reliable and secure.

The chosen diode belongs to the ultra-fast family, and it is the UF4007. Its specifications are as follows:

<p align="center">
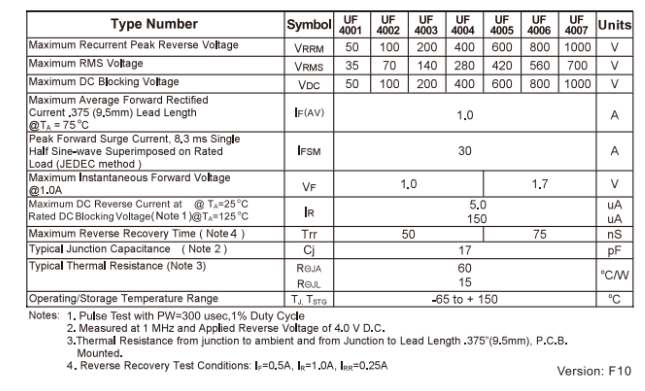
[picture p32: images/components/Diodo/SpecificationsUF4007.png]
UF4007 specification
  
</p>

The most important parameters are in the table below:

<table align="center">
  <thead>
    <tr>
      <th><strong>Parameter</strong></th>
      <th><strong>Value</strong></th>
      <th><strong>Unit</strong></th>
    </tr>
  </thead>
  <tbody>
    <tr>
      <td>Reverse Recovery Time (nS)</td>
      <td>75</td>
      <td>nS</td>
    </tr>
    <tr>
      <td>Maximum Reverse Voltage (V)</td>
      <td>-1000</td>
      <td>V</td>
    </tr>
    <tr>
      <td>Average Current (A)</td>
      <td>1</td>
      <td>A</td>
    </tr>
  </tbody>
</table>

It is evident that the component's datasheet values satisfy the calculated values.

## Thermical Calculation

Just like the MOSFET, the thermal calculation of the diode is necessary to verify if its junction temperature during operation does not exceed the maximum value defined by the datasheet. To do this, some information such as the voltage at the operating point and the diode resistance is required, along with the energy stored in the parasitic capacitance. The datasheet and some equations will be used to obtain these parameters.

To obtain the maximum voltage, it is necessary to know the maximum current that the diode is subjected to. Once calculated, simply refer to the graph in the figure below and find the voltage that corresponds to the calculated current. It is calculated using the formula below.

$$ I_{doMax} = I_{Ro} + \frac{\Delta L_o}{2} $$

<p align="center">
  Forward Voltage
</p>

To obtain the diode's resistance in conduction, the same graph is used. It is known that the derivative of the Current vs. Voltage curve gives the resistance. Therefore, two points close to each other will be selected so that they approximately form a straight line. The first point is (0.3; 1.2), and the second point is (0.8; 1.4). The equation is below:

$$ R_{Do} = \frac{V_2 - V_1}{I_2 - I_1} $$

To obtain the energy stored in the capacitor in parallel with the diode, the following equations are required:

$$ \frac{di}{dt} = -\frac{V_o}{L_o} $$

$$ Q_{rr} = \frac{T_{rr}^2 \cdot \left( \frac{di}{dt} \right)}{3} $$

The losses in the diode are calculated with the equations below:

$$ P_{\text{cond}} = V_f \cdot I_{\text{DoMed}} + R_{\text{do}} \cdot I_{\text{efc}}^2 $$

$$ P_{\text{bloq}} = Q_{\text{rr}} \cdot F_s \cdot |V_{\text{DoMax}}| $$

$$ P_{\text{total}} = P_{\text{cond}} + P_{\text{bloq}} $$

<table align="center">
  <thead>
    <tr>
      <th><strong>Parameter</strong></th>
      <th><strong>Value</strong></th>
      <th><strong>Unit</strong></th>
    </tr>
  </thead>
  <tbody>
    <tr>
      <td>Maximum Current</td>
      <td>0.28</td>
      <td>A</td>
    </tr>
    <tr>
      <td>Forward Voltage (Vf)</td>
      <td>1.2</td>
      <td>V</td>
    </tr>
    <tr>
      <td>Diode Resistance</td>
      <td>0.4</td>
      <td>Ω</td>
    </tr>
    <tr>
      <td>di/dt</td>
      <td>-4490</td>
      <td>A/s</td>
    </tr>
    <tr>
      <td>Qrr</td>
      <td>8.42</td>
      <td>nC</td>
    </tr>
    <tr>
      <td>Conduction Power (Pcond)</td>
      <td>0.298</td>
      <td>W</td>
    </tr>
    <tr>
      <td>Blocking Power (Pbloq)</td>
      <td>1.83E-04</td>
      <td>W</td>
    </tr>
    <tr>
      <td>Total Power</td>
      <td>0.299</td>
      <td>W</td>
    </tr>
  </tbody>
</table>

With the necessary information gathered, it is now possible to calculate the junction temperature of the diode without the presence of a heatsink. The table below contains the required information for the calculation. The equation that gives the junction temperature is exactly the same as the one used for the MOSFET.

<table align="center">
  <thead>
    <tr>
      <th><strong>Parameter</strong></th>
      <th><strong>Value</strong></th>
      <th><strong>Unit</strong></th>
    </tr>
  </thead>
  <tbody>
    <tr>
      <td>Maximum Junction Temperature</td>
      <td>150</td>
      <td>°C</td>
    </tr>
    <tr>
      <td>Maximum Junction Temperature (C.S)</td>
      <td>112.5</td>
      <td>°C</td>
    </tr>
    <tr>
      <td>Ambient Temperature</td>
      <td>50</td>
      <td>°C</td>
    </tr>
    <tr>
      <td>Junction-to-Ambient Resistance</td>
      <td>60</td>
      <td>°C</td>
    </tr>
    <tr>
      <td>Junction Temperature Without Heatsink</td>
      <td>67.90</td>
      <td>°C</td>
    </tr>
  </tbody>
</table>

It is clear that the junction temperature is well below the maximum temperature, even when considering the safety factor. Therefore, it can be concluded that the UF4007 diode is suitable for operation.

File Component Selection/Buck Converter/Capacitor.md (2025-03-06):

# Capacitor Co

The capacitor Co must be capable of handling the effective current it will be subjected to, have a voltage rating higher than the output voltage, and a capacitance greater than the value calculated in the theorical calculations. Additionally, it should exhibit low impedance at high frequencies, minimizing losses and improving overall performance

## Calculated Parameters for the Capacitor

<table align="center">
  <thead>
    <tr>
      <th><strong>Parameter</strong></th>
      <th><strong>Value</strong></th>
      <th><strong>Unit</strong></th>
    </tr>
  </thead>
  <tbody>
    <tr>
      <td>$i_{\text{CoRms}}$</td>
      <td>0.022</td>
      <td>A</td>
    </tr>
    <tr>
      <td>Voltage Rating</td>
      <td>15</td>
      <td>V</td>
    </tr>
    <tr>
      <td>Capacitance</td>
      <td>1.28</td>
      <td>µF</td>
    </tr>
  </tbody>
</table>

It should be noted that the values are higher than they would typically be because a safety coefficient of 1.25 was applied, making the design more reliable and secure.

## Selection

The AX series capacitors are well-suited for high-frequency operation, making them an ideal choice for Co. Since the calculated capacitance value is not commercially available, a higher standard value of 22 µF, 50V will be used. Below is the SANYO catalog containing detailed specifications for the selected capacitor. The chosen component is in the third line of the table.

<p align="center">
  System Diagram for Power Supply
</p>

<p align="center">
  Capacitor Paramenteres
</p>

Below is a table with the specifications of the selected component. The minimum number of capacitors required to handle the necessary effective current and the dissipated power were calculated using the formulas below, while the remaining parameters were obtained from the catalog.

<table align="center">
  <thead>
    <tr>
      <th><strong>Parameter</strong></th>
      <th><strong>Value</strong></th>
      <th><strong>Unit</strong></th>
    </tr>
  </thead>
  <tbody>
    <tr>
      <td>Capacitance</td>
      <td>22</td>
      <td>µF</td>
    </tr>
    <tr>
      <td>Effective Current</td>
      <td>0.110</td>
      <td>A</td>
    </tr>
    <tr>
      <td>Voltage Rating</td>
      <td>50</td>
      <td>V</td>
    </tr>
    <tr>
      <td>Number of Capacitors (N)</td>
      <td>1</td>
      <td>-</td>
    </tr>
    <tr>
      <td>Impedance</td>
      <td>0.7</td>
      <td>Ω</td>
    </tr>
    <tr>
      <td>Dissipated Power</td>
      <td>0.00022</td>
      <td>W</td>
    </tr>
  </tbody>
</table>

Comparing the calculated values with those of the real component, it is evident that the selected component has higher limits than those calculated, making it ideal for the project.

## Equations

$$ N = \left\lceil \frac{i_{\text{CoRms}}}{i_{\text{CoRmsComponent}}} \right\rceil$$

$$ P_{\text{cap}} = \text{Impedance } \cdot I_{\text{CoRms}}^2$$

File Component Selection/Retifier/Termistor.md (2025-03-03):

# Termistor

A thermistor is a resistor that changes its resistance according to temperature. Its function is to limit the current in the rectifier diodes while the power supply is in a transient state. When powered on from the electrical grid, the filter capacitor is discharged, causing the circuit to momentarily draw a high current, which can damage components. Therefore, to size the appropriate thermistor, it is necessary to observe the maximum surge peak current that the diode is capable of conducting. For the 1N4007, this value is 30A. For safety factors, the maximum current will be multiplied by 0.7 for sizing.

To determine the thermistor's resistance at 25°C, the following relation is used:

$$R_{\text{termistor}} = \frac{V_{\text{peakMax}}}{i_{\text{transitoryDiode}}}$$

Knowing that the maximum peak voltage is 329.51 V and the transient current is 21 A, the resistance value for the thermistor is approximately 15 Ω. Since this commercial value was not found, a thermistor with a resistance of 20 Ω at 25°C was chosen.

In operation, the input current tends to heat the thermistor due to the Joule effect, causing the temperature around it to increase and consequently the resistance to decrease, resulting in lower losses to the circuit.

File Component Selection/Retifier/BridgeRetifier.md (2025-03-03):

# Bridfe Retifier

A bridge rectifier consists of four diodes connected in such a way that both the positive and negative half-cycles of the AC waveform are rectified. Although there are components that encapsulate all four diodes, this project will use four separate diodes.

The criteria for selecting a diode were discussed in the section about the DC-DC converter and remain the same: it must withstand the average current and the maximum reverse voltage. Unlike the diodes used in the converter, the rectifier diode does not need to be ultra-fast, since the mains frequency is significantly lower than the switching frequency of the converter.

The average current through the diode is 0.0107 A, and the maximum reverse voltage is 329.51 V. Applying the safety coefficient, the selected diode must have a current rating higher than 0.013375 A and a voltage rating greater than 411 V.

The chosen diode is the 1N4007, a well-known and widely used component in rectifier circuits.

<p align="center">
  1N4007 specifications
</p>

It can be observed from the datasheet that the 1N4007 diode supports a maximum reverse voltage of 700V, which is much higher than the calculated value. It is also evident that it can conduct a forward current of 1A, which is also much higher than all the calculated and simulated currents for the diode. In summary, it is a reliable component for the function it will serve.

<p align="center">
  Forward Voltage
</p>

As discussed in the buck converter section, the curve above is important for obtaining the forward voltage at the operating point and an estimate of the diode's resistance, which are key parameters for thermal calculations. The method to find these quantities has already been discussed earlier. By observing the figure and performing the calculations, it is possible to see that the forward voltage is approximately 0.7V and the resistance is approximately 0.133Ω. Since the frequency is very low, only the conduction losses will be calculated.

<table align="center">
  <thead>
    <tr>
      <th><strong>Parameter</strong></th>
      <th><strong>Value</strong></th>
      <th><strong>Unit</strong></th>
    </tr>
  </thead>
  <tbody>
    <tr>
      <td>Max Reverse Voltage </td>
      <td>329,51</td>
      <td>V</td>
    </tr>
    <tr>
      <td>I med</td>
      <td>0,0107</td>
      <td>A</td>
    </tr>
    <tr>
      <td>Power Loss</td>
      <td>0,0079</td>
      <td>W</td>
    </tr>
    <tr>
      <td>Junction Temperature</td>
      <td>50,79</td>
      <td>ºC</td>
    </tr>
  </tbody>
</table>

It is possibile to see that the chosen component has greater limits then the calculated above.

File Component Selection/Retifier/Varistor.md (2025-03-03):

# Varistor

The varistor serves to protect the circuit from voltage spikes. This type of component has a nominal voltage value, and when this value is exceeded, it operates as if it were a short circuit, causing the current to flow through it instead of reaching the circuit.

Below, you can see a Voltage vs. Current graph comparing a varistor with a standard resistor.

<p align="center">
  Varistor IXV curve
</p>

To select the varistor, it is necessary to consider the maximum RMS operating voltage of the switched-mode power supply and choose a component with a nominal voltage higher than this value. For this project, the RMS voltage is 233 V, so the selected varistor must have a nominal voltage of at least 291.25 V (after applying the safety coefficient).

The chosen component is the S05K300, which has a nominal voltage of 300 V, providing a sufficient margin even with the applied safety coefficient.

<p align="center">
  Varistor
</p>

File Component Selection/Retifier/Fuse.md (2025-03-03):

# Fuse

The fuse serves to protect the switched-mode power supply from a current exceeding the designed limit. The component is connected in series with the circuit so that when it detects a current above the nominal value, it blows, creating an open circuit and preventing current from flowing from the power grid to the power supply.

To select the ideal fuse for the circuit, it is necessary to determine the effective current flowing through it, which corresponds to the input current of the rectifier. Through simulation, we observed that its value is 0.091 A. Therefore, the fuse should have a nominal current higher than the simulated value multiplied by a safety factor, resulting in a minimum nominal current of 0.113 A. Thus, the selected fuse will have a nominal current of 0.2 A.

An image of the selected fuse follows bellow:

<p align="center">
  Fuse Image
</p>

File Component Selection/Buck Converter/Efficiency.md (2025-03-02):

## Efficiency of the Buck Converter

The efficiency of the converter can be calculated using the losses in the components calculated earlier. The converter efficiency resulted in 0.748, and the following equations were used:

$$
P_{\text{total}} = P_{\text{inductor}} + P_{\text{mosfet}} + P_{\text{diode}} + P_{\text{capacitor}}
$$

$$
\eta = \frac{P_o}{P_o + P_{\text{total}}}
$$

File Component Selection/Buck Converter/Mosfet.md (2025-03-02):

# Mosfet

When selecting the MOSFET, there are some key points to consider. Usually, it's sufficient to choose one with a drain-to-source voltage greater than the maximum calculated voltage and a drain current higher than the effective current that will flow through the component.

However, integrated circuits that contain an internal MOSFET are often used. These circuits perform closed-loop control of the output voltage and generate the PWM signal to switch the MOSFET. Using these components reduces the overall project cost, decreases the final PCB size, minimizes the number of components required for soldering, and provides an easy solution for generating the PWM signal that controls the switch. Due to these advantages, the LNK306-DG IC will be used in this project.

This IC contains an internal MOSFET and a PWM pulse generator, as well as a closed-loop control circuit for the output voltage, ensuring that it remains stable and at the designed value.

It is necessary to verify if the internal MOSFET can support a drain-to-source voltage higher than the calculated value for the worst-case scenario, as well as whether it can safely conduct the current required for the operation of the power supply.

Unlike usual, this IC does not provide the drain current that the switch can conduct in its datasheet. Instead, it provides the current variation rate that will trigger the overcurrent protection circuit. Therefore, to verify if the IC is suitable for use in the power supply, it is necessary to calculate the variation rate of the current and use the datasheet information for verification. It is calculated using the equation below:

$$
\frac{di}{dt} = \frac{V_{\text{peakMax}} - \Delta V_{\text{Cin}} - V_o}{L_o}
$$

<table align="center">
  <thead>
    <tr>
      <th><strong>Parameter</strong></th>
      <th><strong>Value</strong></th>
      <th><strong>Unit</strong></th>
    </tr>
  </thead>
  <tbody>
    <tr>
      <td>Drain-Source Voltage (Vds)</td>
      <td>411.88</td>
      <td>V</td>
    </tr>
    <tr>
      <td>Maximum Current</td>
      <td>0.25</td>
      <td>A</td>
    </tr>
    <tr>
      <td>Average Current</td>
      <td>0.025</td>
      <td>A</td>
    </tr>
    <tr>
      <td>RMS Current</td>
      <td>0.089</td>
      <td>A</td>
    </tr>
    <tr>
      <td>Di/Dt</td>
      <td>144.85</td>
      <td>mA/µs</td>
    </tr>
  </tbody>
</table>

It should be noted that the values are higher than they would typically be because a safety coefficient of 1.25 was applied, making the design more reliable and secure.

<p align="center">
  Absolute Max Ratings
</p>

It can be observed in the datasheet of the IC that its internal MOSFET has a maximum voltage rating of 700 V, which is more than sufficient for the project. Regarding the current, it will be necessary to refer to the figures below.

<p align="center">
  Normalized Current Limit
</p>
<p align="center">
  Circuit Protection
</p>

To verify whether the current will be a problem for using this IC, it is necessary to calculate the di/dt in the MOSFET, which has already been done above, and check the resulting current limit value. If the current limit is lower than the calculated value, it means that the IC cannot be used.

Through the first figure, it can be observed that two points are provided: (95;450) and (610;508). The point on the X-axis represents the calculated di/dt, while the point on the Y-axis represents the maximum di/dt that will trigger the protection circuit. These points were chosen because they cover the worst-case scenario for the operation of the LNK306. It can be seen in the figure that the curve is a straight line, and with two points from this line, it is possible to find the equation that represents it. The equation and the resulting maximum current limit are shown below:

$$
\frac{di}{dt_{\text{máx}}} = 0,1126 \cdot \frac{di}{dt_{\text{calc}}} + 439,30
$$

$$
\frac{di}{dt_{\text{máx}}} = 455,61 \, \text{mA/μs}
$$

It is evident that the obtained value is significantly higher than the previously calculated value, allowing the internal MOSFET of the IC to conduct the required current for the operation of the switch-mode power supply without triggering the protection circuit.

## Thermical Calculation

To ensure proper MOSFET operation, its junction temperature during power supply operation must remain below the maximum temperature specified in the datasheet. To approximate the junction temperature without a heatsink, it is necessary to know the thermal resistance in °C/W between the junction and the ambient, as well as the ambient temperature in which the component operates. Additionally, the MOSFET's internal resistance while conducting and its rise and fall times are required. The obtained result should be compared with the maximum junction temperature supported by the IC, which is 150°C according to the datasheet. The maximum junction temperature was multiplied by 0.7 and further adjusted with the project's safety coefficient.

The information in the table below was extracted from the datasheet. The calculations performed were aimed at determining the power dissipation and the junction temperature without a heatsink.

<table align="center">
  <thead>
    <tr>
      <th><strong>Parameter</strong></th>
      <th><strong>Value</strong></th>
      <th><strong>Unit</strong></th>
    </tr>
  </thead>
  <tbody>
    <tr>
      <td>Maximum Junction Temperature</td>
      <td>135</td>
      <td>°C</td>
    </tr>
    <tr>
      <td>Maximum Junction Temperature (S.C.)</td>
      <td>101.25</td>
      <td>°C</td>
    </tr>
    <tr>
      <td>Ambient Temperature</td>
      <td>50</td>
      <td>°C</td>
    </tr>
    <tr>
      <td>Junction-to-Ambient Thermal Resistance</td>
      <td>70</td>
      <td>°C/W</td>
    </tr>
    <tr>
      <td>Junction Temperature Without Heatsink</td>
      <td>64.71</td>
      <td>°C</td>
    </tr>
    <tr>
      <td>Rds On</td>
      <td>12.9</td>
      <td>mΩ</td>
    </tr>
    <tr>
      <td>Rise Time Tr</td>
      <td>50</td>
      <td>ns</td>
    </tr>
    <tr>
      <td>Fall Time Tf</td>
      <td>50</td>
      <td>ns</td>
    </tr>
    <tr>
      <td>Conduction Power Pcond</td>
      <td>0.065</td>
      <td>W</td>
    </tr>
    <tr>
      <td>Switching Power Pcom</td>
      <td>0.144</td>
      <td>W</td>
    </tr>
  </tbody>
</table>

## Equations to Calculate Temperature

$$ T_j = P_{\text{total}} \cdot R_{\text{ja}} + T_a $$

$$ P_{\text{cond}} = R_{\text{ds(on)}} \cdot I_{\text{sRms}}^2 $$

$$ P_{\text{com}} = \frac{F_s \cdot (T_r + T_f) \cdot I_{\text{sMax}} \cdot V_{\text{peakMin}}}{2} $$

$$ P_{\text{total}} = P_{\text{cond}} + P_{\text{com}} $$

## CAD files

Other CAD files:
Hardware/3d View/SwitchModePowerSupply.f3d

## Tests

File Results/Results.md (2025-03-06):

# Results

This section presents measurements of the switched-mode power supply (SMPS) taken with an oscilloscope. Following that, a discussion section will analyze the results. The measurements were made with a 50-ohm load on the power supply.

## Vin

This is the waveform of the input voltage from the electrical grid.

<p align="center">
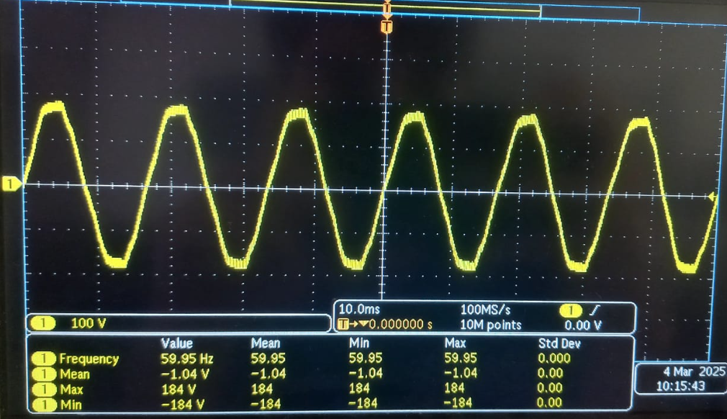
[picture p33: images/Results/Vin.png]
Vin
  
</p>

## Vdin

This is the waveform of the voltage across one of the rectifier diodes.

<p align="center">
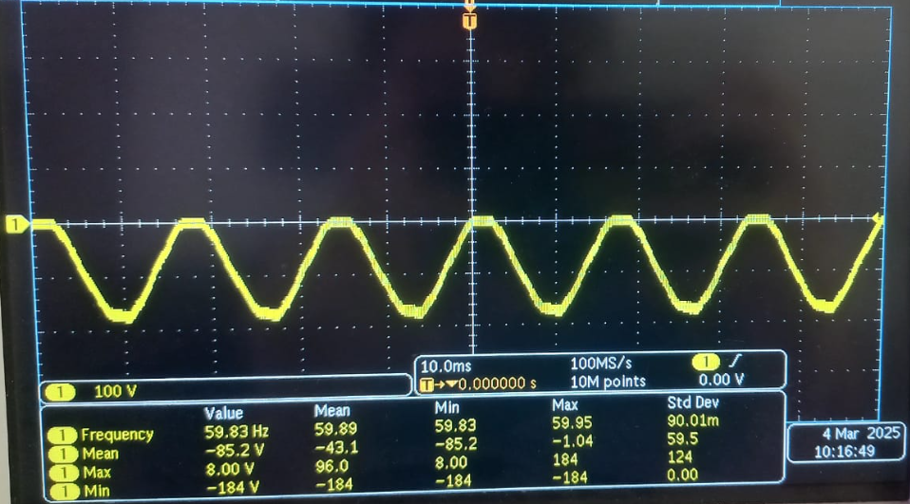
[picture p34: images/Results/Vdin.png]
VDin
  
</p>

## Vx

This is the waveform of the output voltage from the rectifier, which serves as the input to the Buck converter. It is also the same waveform as the filter capacitor voltage.

<p align="center">
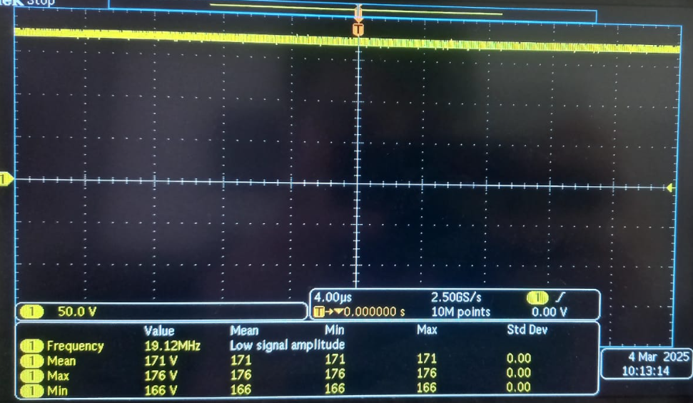
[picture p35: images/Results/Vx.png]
Vx
  
</p>

## Vmosf

This is the waveform of the voltage between the drain and source of the MOSFET.

<p align="center">
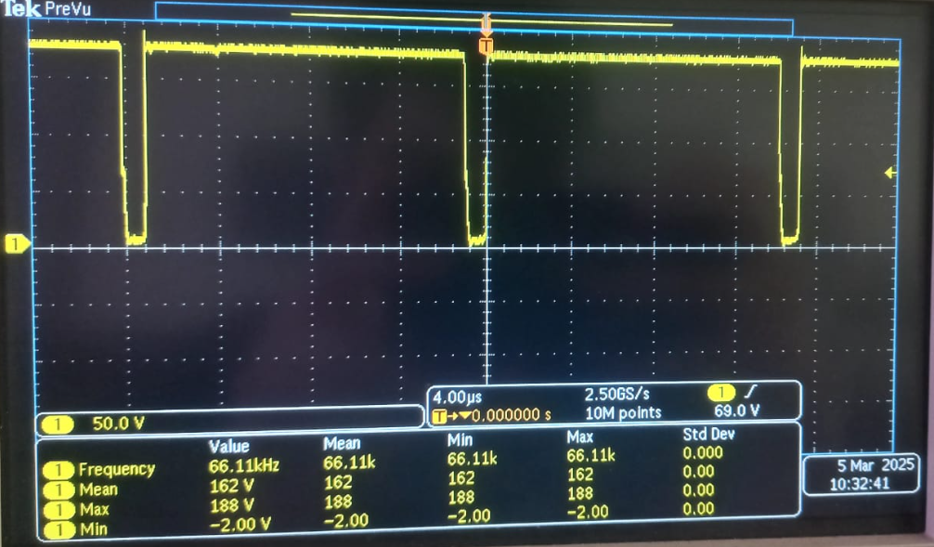
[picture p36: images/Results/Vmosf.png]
Vmosf
  
</p>

## VDo

This is the waveform of the voltage across the diode of the Buck converter.

<p align="center">
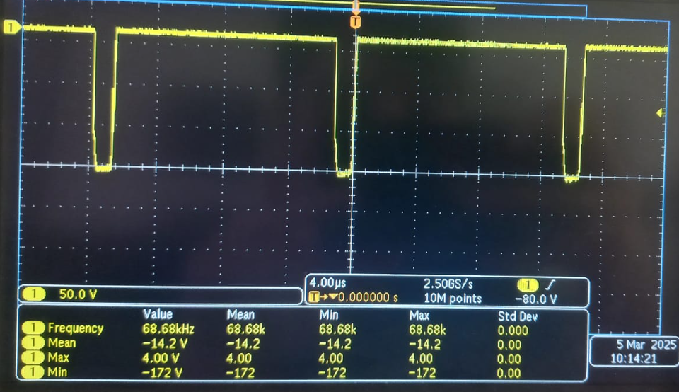
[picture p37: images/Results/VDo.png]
Vdo
  
</p>

## VLo

This is the waveform of the voltage across the inductor Lo.

<p align="center">
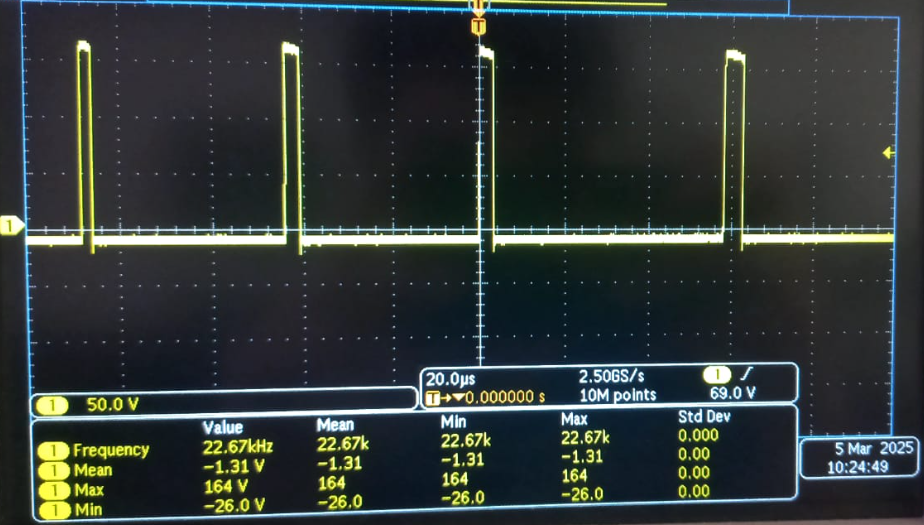
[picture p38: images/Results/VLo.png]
VLo
  
</p>

## Vout

This is the waveform of the output from the switched-mode power supply.

<p align="center">
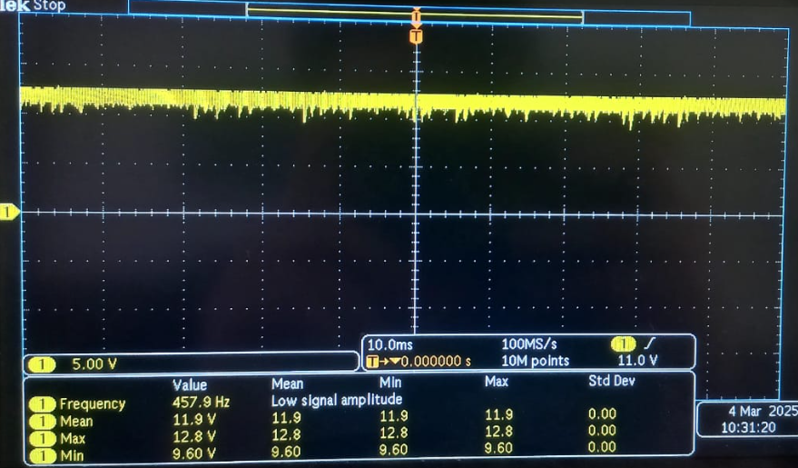
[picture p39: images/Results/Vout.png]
Vout
  
</p>

## Discussion

The waveforms of the rectifier were exactly as expected. The grid had an RMS voltage of approximately 130V, which was within the expected range, with a frequency of approximately 60 Hz, which is correct for Brazil.

The voltage across the diode behaved as anticipated, conducting during one half-cycle of the sine wave, while being blocked during the other half-cycle.

The rectifier output voltage exhibited a ripple of 5.85%, slightly higher than the design target of 5%. The ripple was calculated by observing only the image of Vx, which shows a different maximum voltage compared to the maximum voltage in the Vin image, likely due to the oscilloscope’s timebase settings during the measurements.

$$ \text{Ripple} = \left( \frac{V_{\text{ripple}}}{V_{\text{DC}}} \right) \times 100 $$

$$ V_{\text{ripple}} = V_{\text{max}} - V_{\text{min}} $$

$$ V_{\text{DC}} = \frac{V_{\text{max}} + V_{\text{min}}}{2} $$

In the Buck converter, the MOSFET voltage waveform matched expectations, showing that most of the time the MOSFET is not conducting. This is expected since the converter's gain is relatively small.

The diode voltage waveform exhibited the expected complementary behavior, with the diode conducting most of the time, as theorized, while the MOSFET is off.

The frequencies of these two waveforms closely match the value provided in the datasheet, which specifies a typical frequency of 66 kHz.

The waveform of the voltage across the inductor exhibited the correct shape: when the MOSFET is on, the inductor has a positive voltage, and when the MOSFET is off, the inductor exhibits a negative voltage. This is as expected based on the theory. What deviates from the standard is the frequency measurement, as it should match the frequency of the MOSFET and the diode.

This discrepancy is due to the on/off control method of the LNK306 IC, which causes the MOSFET to remain off for several cycles. As a result, the converter frequency is lower than 66 kHz during certain periods.

The output voltage of the power supply is measured at a mean value of 11.9V, which is very close to the designed value, with an average current of 0.238 A. This results in a power output of approximately 2.83 W, slightly less than the targeted 3 W. This discrepancy can be attributed to practical losses not accounted for in the theoretical calculations, such as losses in the PCB traces, cables, and the NTC resistor. Additionally, component tolerance and error factors may contribute to a higher actual power dissipation than what was calculated theoretically.

Although the IC exhibits some limitations in its control method, such as its on/off regulation, which affects the switching frequency, the power supply has still demonstrated satisfactory performance. The observed deviations, like the lower than expected frequency and minor ripple in the output voltage, do not significantly impact its overall functionality. The design could be improved by adding shunt resistors to measure currents across components, which would provide a more comprehensive understanding of the system's performance and losses.

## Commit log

2025-01-25 Files Creation
    [SwitchModePowerSupply.f3d]
2025-01-25 Equations Buck Converter
2025-01-28 Initial of SwitchPowerSupplr Module
2025-02-26 images and buck simulation
2025-03-02 Switch Power Suplly simulations
2025-03-02 Therocial vs simulatiuon Buck
2025-03-02 Capacitor Co selection
2025-03-02 Mosfet selection
2025-03-02 Diode Do
2025-03-02 Add extra table in diode component selection
2025-03-02 Center Theory Buck Converter
2025-03-03 Filter Capacitor
2025-03-03 Voltage Sensor
2025-03-03 hardware Read me pics of PCB
2025-03-06 Capacitor cetralized
2025-03-06 Center capacitor last table
2025-03-06 Fix in capacitor section
2025-03-06 Fix in diode section
2025-03-06 Fix in voltage Sensor
